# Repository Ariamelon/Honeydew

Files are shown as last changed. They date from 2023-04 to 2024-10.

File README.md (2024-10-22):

# Honeydew
~60% 63-key QMK-compatible unified split ergonomic keyboard with [VIK](https://github.com/sadekbaroudi/vik) module support.

## Disclaimer
This keyboard is licensed under CERN-OHL-S-2.0, runs [QMK Firmware](https://qmk.fm/) and is compatible with the [VIK](https://github.com/sadekbaroudi/vik) standard. The layout is based on the [Cantaloupe](https://github.com/Ariamelon/Cantaloupe) layout, but with each half rotated 15 degrees inwards. The CNC aluminium top half of the keyboard case in the image was sponsored by [PCBWay](https://www.pcbway.com/).

## Key Features
* Ergonomic unsplit 60-key vertically staggered layout with thumb cluster, pinky stagger and arrow keys, plus 3 keys around a center VIK module spot and a 2.25u key below that.
* Thumb scroll wheel at bottom of keyboard, replacing the 2.25u key in that position.
* Each half rotated 15 degrees inwards.
* On-board STM32F072RBT6 processor.
* SWD header for debugging purposes.
* USB-C input with full ESD protection.
* MX and choc hotswap switch support with kailh hotswap sockets.
* Per-key RGB backlight and ARGB header for adding more.
* Gasket-mount case supporting 65 x 4 x 4mm gaskets with 25% compression (14 required).
* [Acheron single-push reset circuit](https://acheronproject.com/reset_article_1/reset_article_1/#52-substituting-the-jfet).

## VIK keyboard certification card
| Category | Classification | Response |
| ---  | --- | --- |
| FPC connector | Required | :heavy_check_mark: |
| Breakout pins | Recommended | :heavy_check_mark: |
| Supplies: SPI | Strongly recommended | :heavy_check_mark: |
| Supplies: I2C | Strongly recommended | :heavy_check_mark: |
| I2C on main PCB | Discouraged | No |
| I2C pull ups | Informative | N/A |
| Supplies: RGB | Strongly recommended | :heavy_check_mark: |
| Supplies: Extra GPIO 1 | Required | Analog/Digital |
| Supplies: Extra GPIO 2 | Required | Analog/Digital |

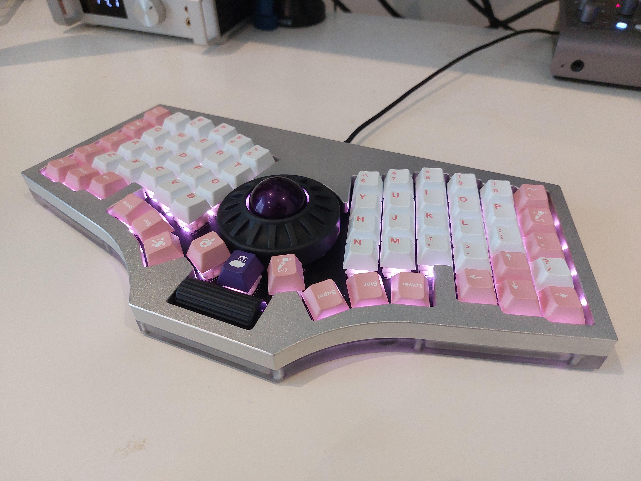
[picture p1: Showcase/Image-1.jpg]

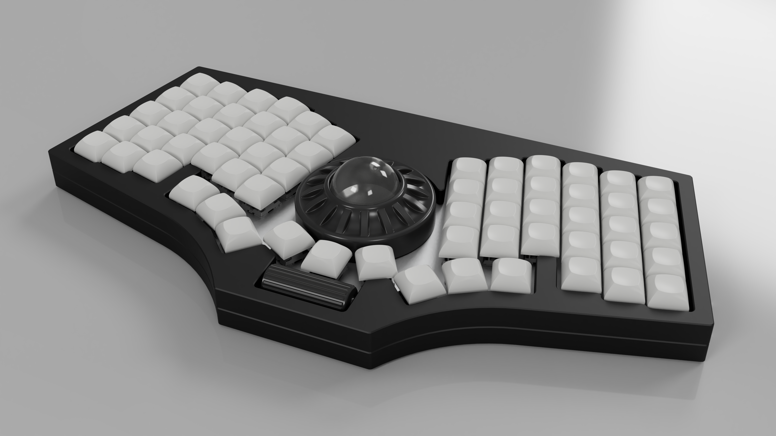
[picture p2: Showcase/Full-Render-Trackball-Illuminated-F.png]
Full Render Trackball Illuminated Front

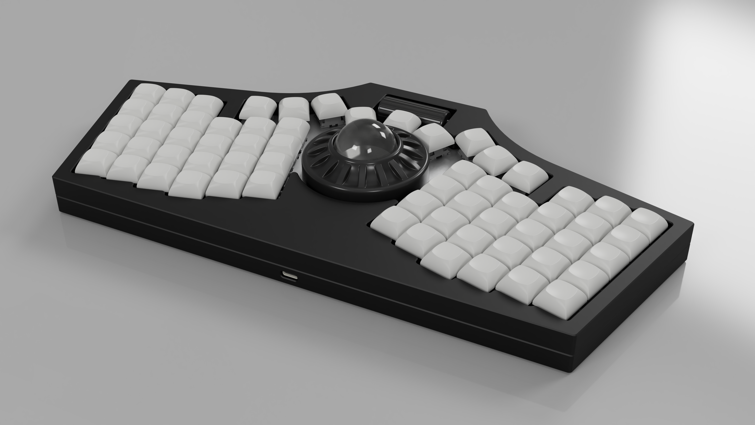
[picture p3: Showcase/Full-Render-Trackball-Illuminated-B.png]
Full Render Trackball Illuminated Back

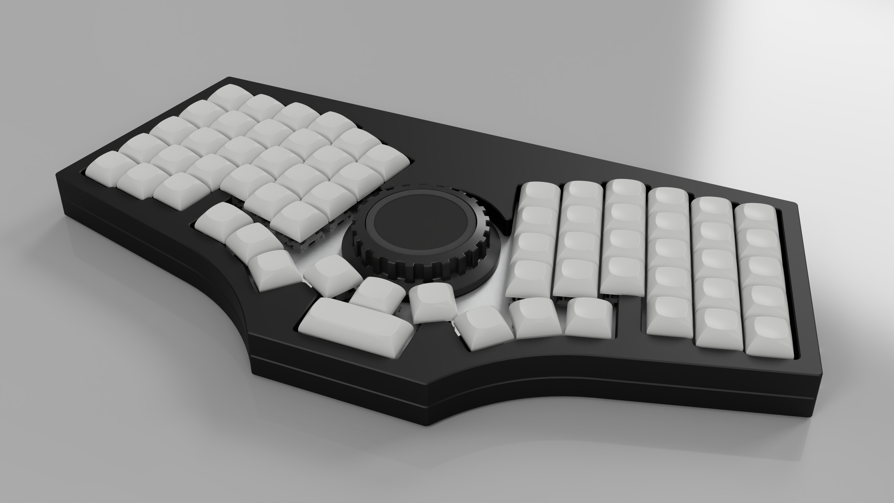
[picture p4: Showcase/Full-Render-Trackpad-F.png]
Full Render Trackpad Front

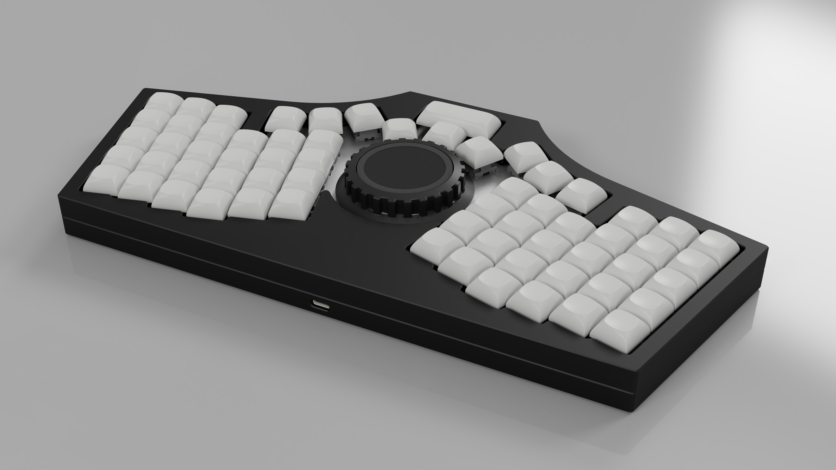
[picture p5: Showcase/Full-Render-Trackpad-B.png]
Full Render Trackpad Back

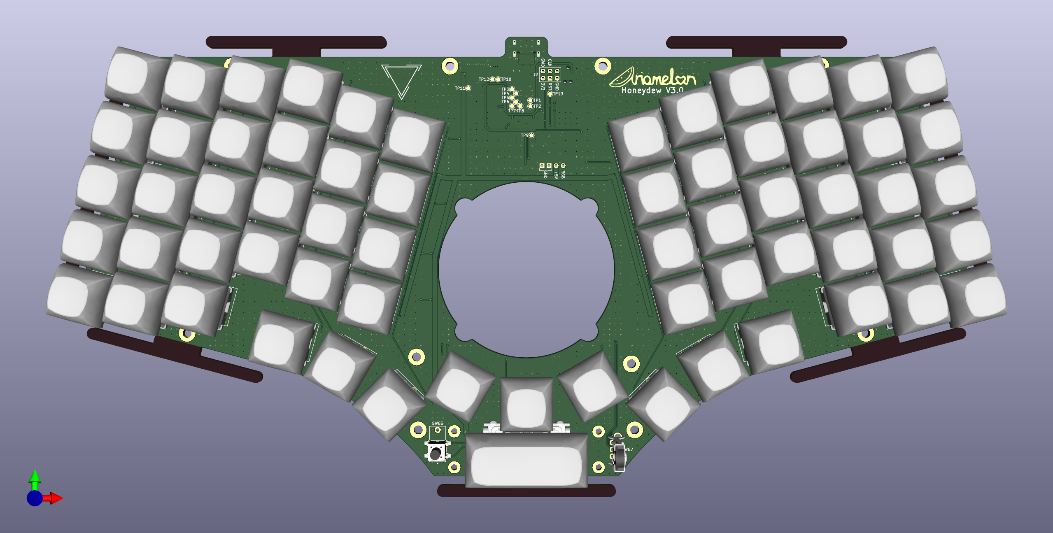
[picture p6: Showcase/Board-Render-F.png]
Board Render Front

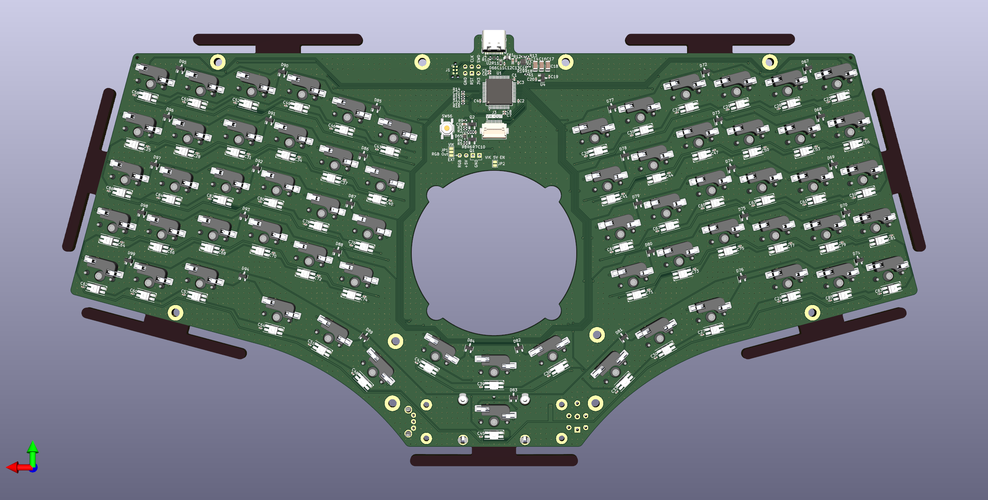
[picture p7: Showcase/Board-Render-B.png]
Board Render Back


## Changelog
* 22/10/2024: License updated to CERN-OHL-S-2.0.
* 29/09/2023: Added PCBWay sponsorship disclaimer to the readme. Updated library.
* 27/09/2023: Added image. Small change to scrollwheel 3D file for smoother scrolling.
* 18/09/2023: Fixed .gitignore file. Updated library.
* 02/09/2023: Added ribs to bottom case for less warping, deformation and shrinkage risk. Updated library.
* 29/08/2023: Reassigned I2C pins due to DMA issues and rerouted board. Added test point for BOOT0. Added additional ground vias.
* 28/08/2023: Added test points for VIK connector. Refined case and scrollwheel design. Added pull-up resistor to RGB trace. Added Acheron single-push reset circuit. Updated STEP files.
* 27/08/2023: Added unified library for all symbols, footprints and 3D files. Changed MCU to STM32F072RBT6. Removed OLED, voltage and current sensing, USB CC circuitry and shift registers. Changed ESD protection chip. Cleaned up routing and component placement. Changed SWD header pinout to 6-pin standard.
* 17/08/2023: Moved gasket mounts from plate to PCB. Changed USB C connector. Modified case to accommodate.
* 16/08/2023: Fixed VIK wiring (RGB and SDA were swapped). Added another BAV70 for the bottom button in the thumb cluster. Added DNP attribute to R15. Added jumper for VIK 5V rail. 
* 08/08/2023: Fixed case render.
* 06/08/2023: Changed switch footprint back to MX only, as it's too much money to risk on an experimental footprint, and rerouted the relevant traces. Cleaned up footprint library by removing many unused footprints.
* 05/08/2023: Fixed switch and SK6812 MINI-E footprints to get rid of DRC errors. Fixed EC10 footprint and merged together PTS645 and D2F footprints. Fixed plate files to fit JLC 1.6mm minimum slot specification. Added fusion file for overall design.
* 04/08/2023: Updated SK6812 MINI-E and switch footprints. Changed VIK FFC to FH12. Fixed VIK footprint. Replaced second TPS2595 with AO3401 PFET. Fixed trackpad mount, thumb scroll wheel and scroll wheel mount.
* 01/08/2023: Removed 3D files for trackpad mount and knob, moved to [Kiwano](https://github.com/Ariamelon/Kiwano) repository. Increased size of center hole in plate. Added renders with trackball configurations (refer to Kiwano).
* 31/07/2023: Removed button daughterboard. Reduced size of case and gaskets and added locating features. Added o-ring mounting for the PCB to the bottom case. Added fittings BOM.
* 30/07/2023: Added VIK keyboard certification card. Added USB connector back to PCB, but left the two buttons on a separate daughterboard. Modified case to accommodate large VIK module.
* 28/07/2023: Removed center ring encoder, cirque trackpad and PMW3360 support. Added VIK header and hole in the center of the PCB for the [Kiwano](https://github.com/Ariamelon/Kiwano). Changed JST connectors back to 20 pin FFC. Total rearrangement of parts in keyboard center. Stitched ground planes together. Added USB module to board rather than have it be separate.
* 26/07/2023: Slightly increased size of screw hole pads. Added two more screw holes. Added mounting holes to plate. Flipped gerbers for scrollwheel plate.
* 25/07/2023: Changed 8 pin JST SH connector to 6 pin. Pushed JST connectors back. Improved 3D model of SSD1351. Minor fix to PER56 footprint.
* 21/07/2023: Changed 20 pin FFC to 7 pin and 8 pin JST SH connector.
* 18/07/2023: Changed JST connector back to 20 pin FFC. Centered connector. Increased size of PMW3360 cutout.
* 17/07/2023: Changed 20 pin FFC connector to 14 pin JST SH connector. Repositioned components.
* 16/07/2023: Updated case file. Added individual case files. Added kicad plate files.
* 14/07/2023: Replaced 1N4148 switch diodes with BAV70. Replaced switch footprints with combination MX/Choc hotswap footprints. Replaced flash IC with much smaller version. Removed buttons and USB-C port and replaced it with an FFC connector for [Galia](https://github.com/Ariamelon/Galia) (a USB-C daughterboard designed specifically for the Honeydew). Added case STEP file and renders. Added footprint for PTS645 SMT and THT parts to the mouse switch in the thumb encoder.
* 06/07/2023: Replaced 0805 ferrite with 1206. Repositioned components.
* 30/06/2023: Routed 13V EN pin to the MCU. Removed 13V solder jumper.
* 27/06/2023: V3.0 initial update. Wired RST pin of OLED to MCU. Reduced size of OLED FFC cutout. Repositioned components. Added REF3033 3.3V voltage reference and connected it to the ADC input. Added pullup to RGB current limit switch enable input. 
* 11/06/2023: Updated BOM. Added new tentative plate file. Updated 3D files.
* 20/05/2023: Added scroll wheel rotary encoder and mouse switch for thumb scroll wheel, replacing bottom 2u key.
* 19/05/2023: Improved switch footprints. Changed 3v3 regulator to XC6206P332MR.
* 15/05/2023: Finished routing RGB LEDs.
* 05/05/2023: Changed PMOS switch to TPS2595, set to ~3A current limit. Got rid of RGB current measurement. Added enable jumper for 13V OLED PSU (only jump when in use to reduce noise when not in use). Still not done with RGB LED routing.
* 25/04/2023: Added current and voltage measurement for VBUS in and current measurement for the RGB output. Added PMOS power switch to fully turn off RGB LEDs when not in use. Rerouted the PCB. Moved OLED ribbon cable cutout and expanded it length-wise. Changed position of various components for better routing. Changed bulk capacitance of RGB LEDs to 5 x 22u capacitors. Changed the four N mosfets to two much smaller dual N mosfets. Still need to do RGB routing!
* 17/04/2023: Large update. Changed position of thumb buttons and added another button. Revamped shape of PCB again. Changed PER60 to PER56. Added 30-pin FFC receptacle for direct OLED panel mounting to the PCB (lower profile). Now using 595 shift registers for columns. Increased number of LEDs in central LED ring. Changed current limiting device to TPS2595. Connected current limiting ICs to MCU, allowing for software monitoring of current levels and changing of allowed current. Removed individual RGB capacitors and added bulk capacitance.
* 10/04/2023: Shrunk size of PCB. Added plate DXF and gerbers. Removed split comms ports and ideal diode.
* 08/04/2023: Large update. Removed single-push reset circuit, added side buttons next to the USB ports. Added pi filter to VBUS and split comms ports for more voltage filtering. Completely revamped shape of PCB for more space efficiency. Pushed each side further out and OLED further down. Added TUSB320 CC logic controller and TPS2557 current limit switch to allow the board to safely draw up to 15W (5V 3A) of power. Added mounting holes on PCB. Removed ferrite between USB shield and ground. Replaced back to back P-mosfets with ideal diode setup. Removed QMK logo (sorry). Cleaned up schematic somewhat. Added large caps to output of TPS2557. Updated STEP file and file data. Added back ground plane. Fixed rotation of production files.
* 03/04/2023: Changed level shifter to cheaper model. Slightly changed USB-C footprint. Added single-push reset circuit and removed DIP switch. Updated readme and STEP file. Moved position of USB-C ports further out.
* 02/04/2023: Changed angle of each unsplit half to 15 degrees inwards instead of 20 degrees with corresponding change to PCB and plate shape. Re-did 5V routing on the board. Added ARGB header to attach external RGB strips. Removed reverse voltage/current schottky and added back to back P-mosfets to provide the same function. Added ferrite bead to VBUS for more voltage filtering. Changed ESD protection chip to TPD4E05U06DQAR. Added USB-C expansion headers for expansion boards using split comms with the same protections as the primary USB-C input port. Added M3 earth pad for connection to a metal case. Added solder jumper to select OLED voltage as it should work fine when powered by 5V, but the option to power from 3V3 is there if required. Case to follow..
* 31/03/2023: Connected DR (data-ready) pin of TM040040 to Motion pin of PMW3360 as they serve the same function. Connected reset pins to hardware reset button instead of MCU. Added locating features to CNC case, increased wall thickness by 1mm for better magnet support (4mm now instead of 3mm) and increased size of gaskets. Redesigned trackpad mount and rotary encoder knob to allow for the illuminated ring to show up better. Added powered by QMK logo to board.
* 24/04/2023: Added level shifter to the RGB signal, just in case.
* 14/03/2023: Fixed top and bottom case STEP files. Minor fix to silk.
* 13/03/2023: V2.0 initial update. Moved switch footprint center back to normal position. Swapped capacitor and resistor at USB-C connector for ferrite bead. Moved positions of USB VBUS protection. 
* 11/03/2023: Added PH2.0 header for OLED. Changed plate to accommodate headers. Better render.
* 10/03/2023: Fixed OLED description in readme. Changed center of switches for JLC assembly.
* 09/03/2023: Shifted MCU up to reduce length of USB traces. Added holes for JLC assembly. Attempted to render a better quality image.
* 08/03/2023: Added 3D render of case, case STEP files and plate DXF and gerbers.
* 07/03/2023: Rewording of readme. Added files for JLC PCBA. Changed USB C connector and moved it away from board.
* 06/03/2023: Minor repositioning of parts.
* 05/03/2023: Added mounting holes for trackpad/trackball mount. Added CC BY 4.0 license.
* 04/03/2023: Massive mistake corrections and clarifications. Changed 22R USB resistors to 27R. Readded missing pullup for RUN pin. Changed notation of power and ground rails to the standard. Connected RGB LEDs to 5V instead of 3V3. Added keycap model to render. Changed board showcase files from SVG to PDF. Fixed error in MCU sheet. Changed flash symbol to the one used in Kicad 7.
* 03/03/2023: Initial public upload of V1.0.

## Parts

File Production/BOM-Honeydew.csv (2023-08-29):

Comment | Designator | Footprint | LCSC
1k | R4 | R_0402_1005Metric | C11702
10n | C11,C21,C22,C8 | C_0402_1005Metric | C15195
1u | C12 | C_0603_1608Metric | C15849
USB In | J4 | G-Switch_GT-USB-7010ASV | C165948
AO3400A | Q1,Q2 | SOT-23-3 | C20917
1N4148 | D65 | D_SOD-323 | C2128
TPS259533 | U3 | WSON-8-1EP_2x2mm_P0.5mm_EP0.9x1.6mm | C2155777
60R@100MHz | FB1 | L_0805_2012Metric | C237300
4u7 | C1,C5 | C_0402_1005Metric | C23733
100 | R7 | R_0402_1005Metric | C25076
100k | R8 | R_0402_1005Metric | C25741
10k | R13,R14,R15,R16,R17,R5,R6,R9 | R_0402_1005Metric | C25744
12k | R18 | R_0402_1005Metric | C25752
330k | R2 | R_0402_1005Metric | C25778
5k1 | R1,R10,R11 | R_0402_1005Metric | C25905
6k8 | R19 | R_0402_1005Metric | C25917
1M | R3 | R_0402_1005Metric | C26083
100n | C10,C13,C14,C2,C23,C24,C25,C26,C27,C28,C29,C3,C30,C31,C32,C33,C34,C35,C36,C37,C38,C39,C4,C40,C41,C42,C43,C44,C45,C46,C47,C48,C49,C50,C51,C52,C53,C54,C55,C56,C57,C58,C59,C6,C60,C61,C62,C63,C64,C65,C66,C67,C68,C69,C70,C71,C72,C73,C74,C75,C76,C77,C78,C79,C80,C81,C82,C83,C84,C85,C86 | C_0402_1005Metric | C307331
Reset | SW66 | SW_SPST_TL3342 | C318884
STM32F072RBT6 | U1 | LQFP-64_10x10mm_P0.5mm | C46046
SK6812MINI-E | D1,D10,D11,D12,D13,D14,D15,D16,D17,D18,D19,D2,D20,D21,D22,D23,D24,D25,D26,D27,D28,D29,D3,D30,D31,D32,D33,D34,D35,D36,D37,D38,D39,D4,D40,D41,D42,D43,D44,D45,D46,D47,D48,D49,D5,D50,D51,D52,D53,D54,D55,D56,D57,D58,D59,D6,D60,D61,D62,D63,D64,D7,D8,D9 | LED_OPSCO_SK6812MINI-E | C524051
1u | C15,C19,C20,C7 | C_0402_1005Metric | C52923
XC6206P332MR | U4 | SOT-23-3 | C5446
BAV70 | D67,D68,D69,D70,D71,D72,D73,D74,D75,D76,D77,D78,D79,D80,D81,D82,D83,D84,D85,D86,D87,D88,D89,D90,D91,D92,D93,D94,D95,D96,D97,D98,D99 | SOT-23-3 | C68978
5V | D66 | D_SOD-523 | C85708
VIK Keyboard Expansion | J3 | VIK_Keyboard_Horizontal | C88360
TPD2EUSB30A | U2 | Texas_DRT-3 | C94934
47u | C16,C17,C18 | C_1206_3216Metric | C96123
10u | C9 | C_0603_1608Metric | C96446
SWD | J2 | PinHeader_SWD_2x03_P2.54mm_Vertical
CPG151101S11 | SW25 | SW_MX_1U_Hotswap
CPG151101S11 | SW30 | SW_MX_1U_Hotswap
CPG151101S11 | SW1 | SW_MX_1U_Hotswap
CPG151101S11 | SW24 | SW_MX_1U_Hotswap
CPG151101S11 | SW29 | SW_MX_1U_Hotswap
CPG151101S11 | SW14 | SW_MX_1U_Hotswap
CPG151101S11 | SW19 | SW_MX_1U_Hotswap
CPG151101S11 | SW5 | SW_MX_1U_Hotswap
CPG151101S11 | SW22 | SW_MX_1U_Hotswap
CPG151101S11 | SW27 | SW_MX_1U_Hotswap
CPG151101S11 | SW3 | SW_MX_1U_Hotswap
CPG151101S11 | SW8 | SW_MX_1U_Hotswap
CPG151101S11 | SW13 | SW_MX_1U_Hotswap
CPG151101S11 | SW23 | SW_MX_1U_Hotswap
CPG151101S11 | SW18 | SW_MX_1U_Hotswap
CPG151101S11 | SW28 | SW_MX_1U_Hotswap
CPG151101S11 | SW4 | SW_MX_1U_Hotswap
CPG151101S11 | SW9 | SW_MX_1U_Hotswap
CPG151101S11 | SW10 | SW_MX_1U_Hotswap
CPG151101S11 | SW15 | SW_MX_1U_Hotswap
CPG151101S11 | SW20 | SW_MX_1U_Hotswap
CPG151101S11 | SW11 | SW_MX_1U_Hotswap
CPG151101S11 | SW2 | SW_MX_1U_Hotswap
CPG151101S11 | SW12 | SW_MX_1U_Hotswap
CPG151101S11 | SW21 | SW_MX_1U_Hotswap
CPG151101S11 | SW17 | SW_MX_1U_Hotswap
CPG151101S11 | SW16 | SW_MX_1U_Hotswap
CPG151101S11 | SW6 | SW_MX_1U_Hotswap
CPG151101S11 | SW7 | SW_MX_1U_Hotswap
CPG151101S11 | SW26 | SW_MX_1U_Hotswap
CPG151101S11 | SW56 | SW_MX_1U_Hotswap
CPG151101S11 | SW62 | SW_MX_1U_Hotswap
CPG151101S11 | SW50 | SW_MX_1U_Hotswap
CPG151101S11 | SW44 | SW_MX_1U_Hotswap
CPG151101S11 | SW42 | SW_MX_1U_Hotswap
CPG151101S11 | SW63 | SW_MX_1U_Hotswap
CPG151101S11 | SW61 | SW_MX_1U_Hotswap
CPG151101S11 | SW58 | SW_MX_1U_Hotswap
CPG151101S11 | SW34 | SW_MX_1U_Hotswap
CPG151101S11 | SW53 | SW_MX_1U_Hotswap
CPG151101S11 | SW45 | SW_MX_1U_Hotswap
CPG151101S11 | SW33 | SW_MX_1U_Hotswap
CPG151101S11 | SW48 | SW_MX_1U_Hotswap
CPG151101S11 | SW32 | SW_MX_1U_Hotswap
CPG151101S11 | SW37 | SW_MX_1U_Hotswap
CPG151101S11 | SW49 | SW_MX_1U_Hotswap
CPG151101S11 | SW46 | SW_MX_1U_Hotswap
CPG151101S11 | SW55 | SW_MX_1U_Hotswap
CPG151101S11 | SW41 | SW_MX_1U_Hotswap
CPG151101S11 | SW36 | SW_MX_1U_Hotswap
CPG151101S11 | SW35 | SW_MX_1U_Hotswap
CPG151101S11 | SW52 | SW_MX_1U_Hotswap
CPG151101S11 | SW39 | SW_MX_1U_Hotswap
CPG151101S11 | SW40 | SW_MX_1U_Hotswap
CPG151101S11 | SW43 | SW_MX_1U_Hotswap
CPG151101S11 | SW38 | SW_MX_1U_Hotswap
CPG151101S11 | SW60 | SW_MX_1U_Hotswap
CPG151101S11 | SW59 | SW_MX_1U_Hotswap
CPG151101S11 | SW47 | SW_MX_1U_Hotswap
CPG151101S11 | SW31 | SW_MX_1U_Hotswap
CPG151101S11 | SW64 | SW_MX_2U_Hotswap
CPG151101S11 | SW51 | SW_MX_1U_Hotswap
CPG151101S11 | SW54 | SW_MX_1U_Hotswap
CPG151101S11 | SW57 | SW_MX_1U_Hotswap

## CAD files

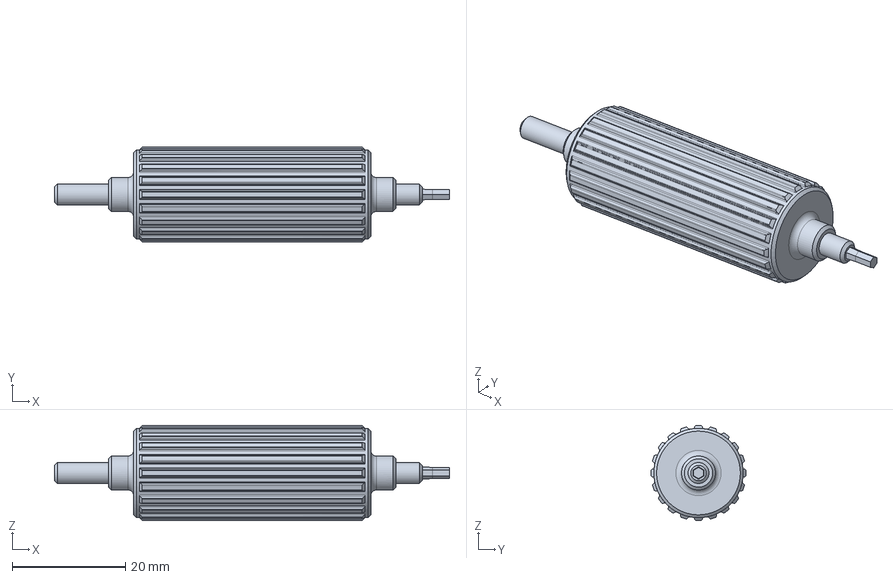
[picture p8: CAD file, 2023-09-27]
Case/Scrollwheel.step
69.8 x 16.8 x 16.8 mm

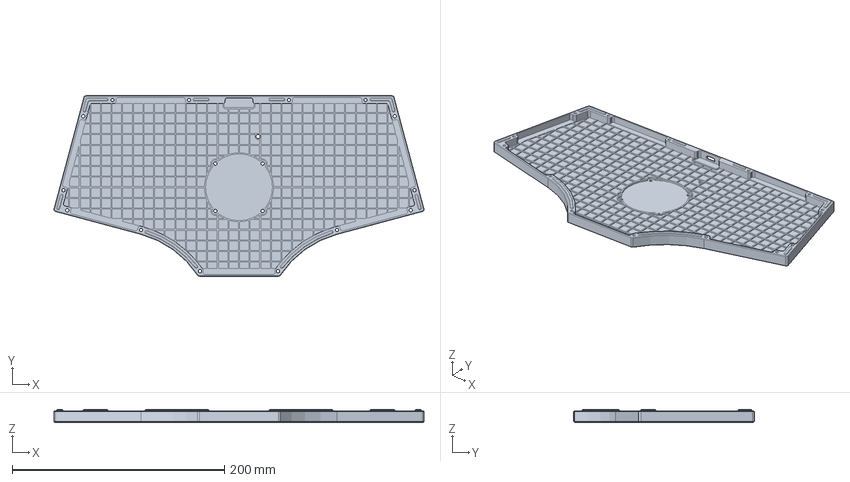
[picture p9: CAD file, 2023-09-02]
Case/Case Bottom.step
348.5 x 170.0 x 11.8 mm

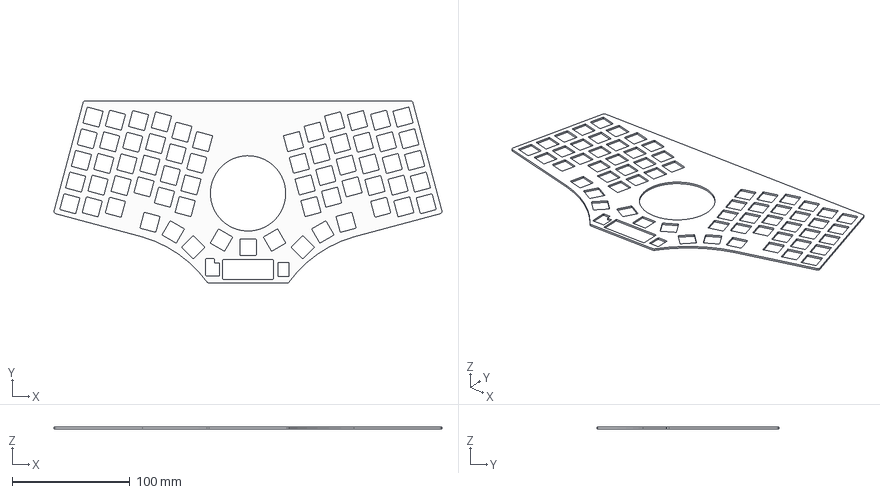
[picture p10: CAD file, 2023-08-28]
Case/Plate Scroll.step
329.6 x 154.8 x 1.50 mm

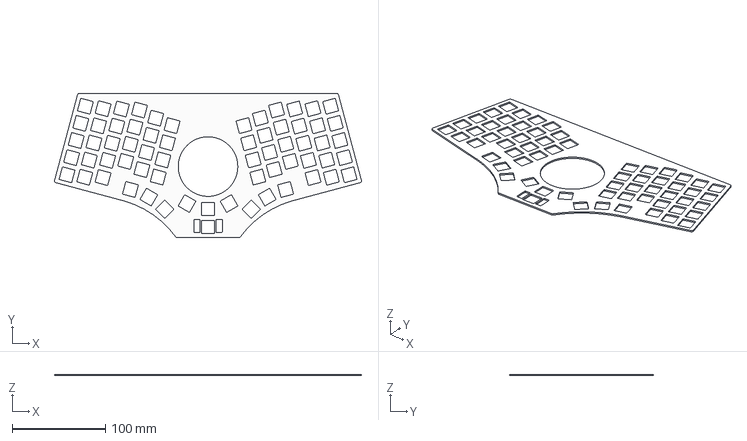
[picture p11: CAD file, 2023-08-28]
Case/Plate 2u.step
329.6 x 154.8 x 1.50 mm

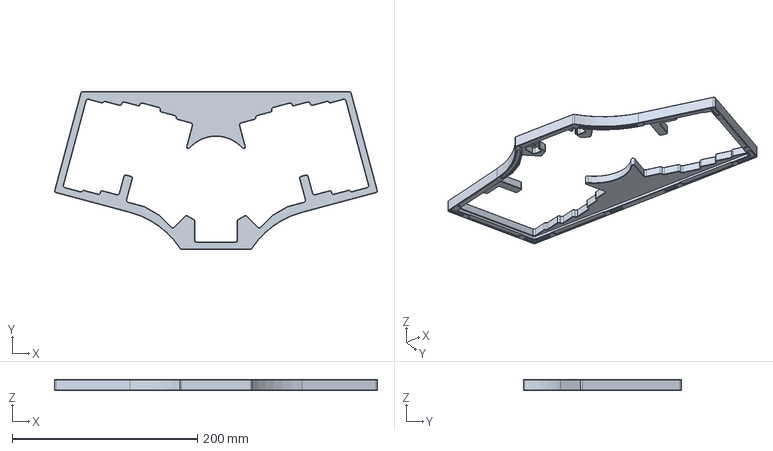
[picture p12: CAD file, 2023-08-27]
Case/Case Top.step
348.5 x 170.0 x 12.2 mm

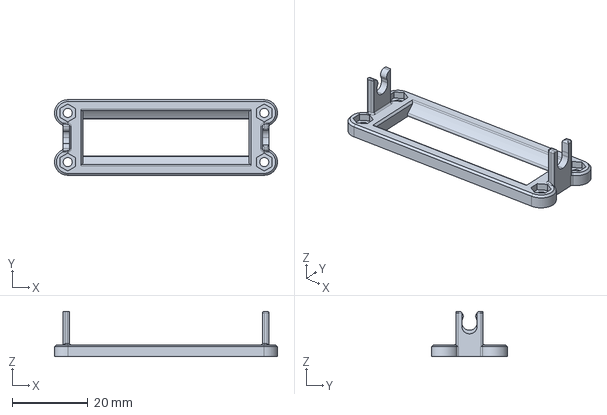
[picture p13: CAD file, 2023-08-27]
Case/Scrollwheel Holder.step
59.0 x 20.0 x 12.0 mm

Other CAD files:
Case/Plate 2u.dxf
Case/Plate Scroll.dxf

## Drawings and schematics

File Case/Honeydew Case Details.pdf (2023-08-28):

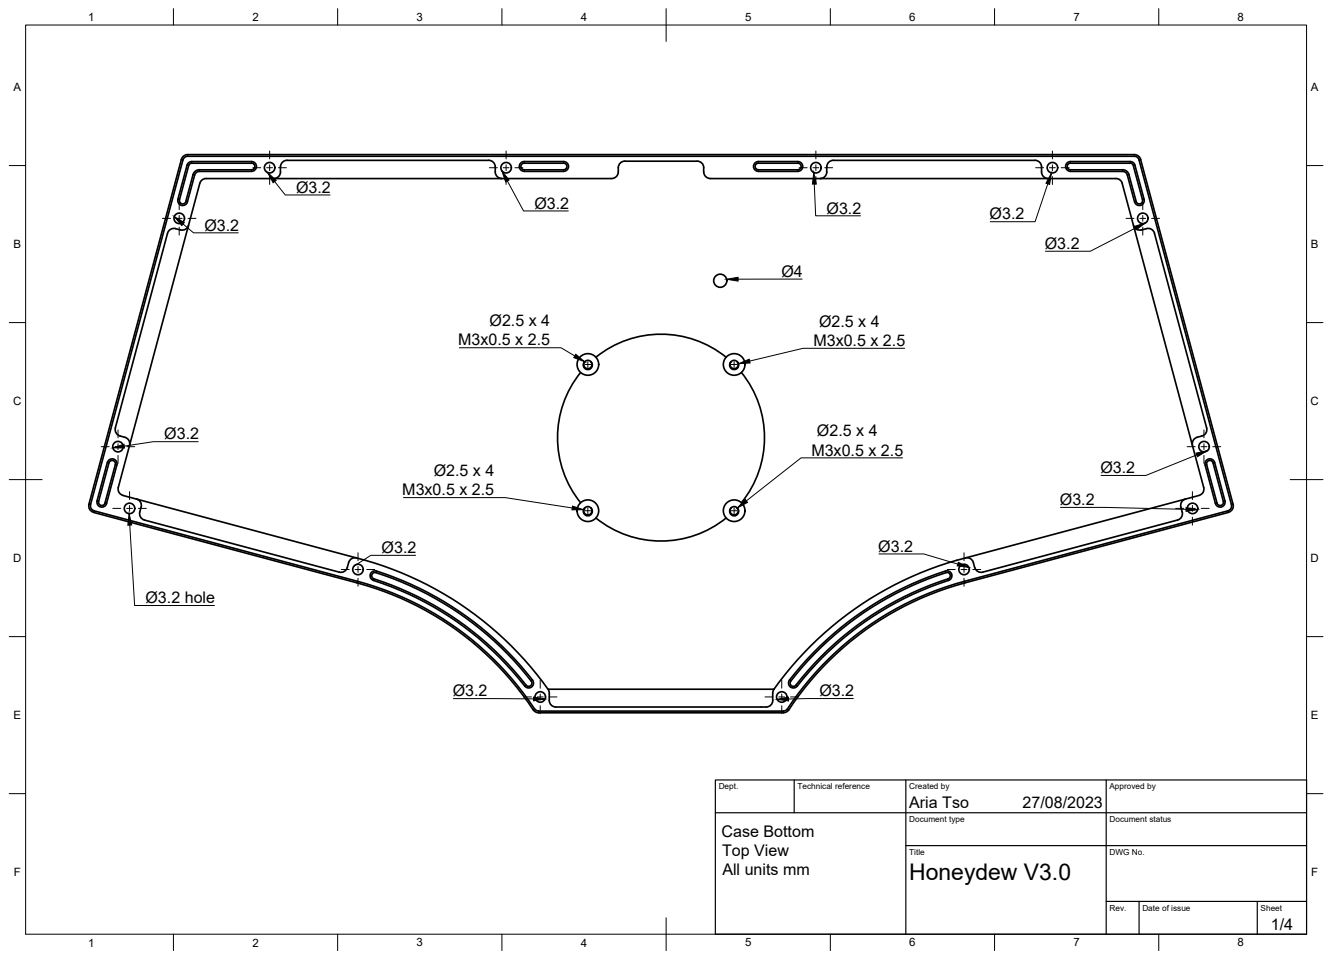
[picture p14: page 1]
Title; DWG No.; Rev.; Date of issue; Sheet; Honeydew V3.0; Ø3.2 hole

Dept. | Technical reference | Created by Aria Tso 27/08/2023 | Approved by

Document type | Document status

Case Bottom
Top View
All units mm

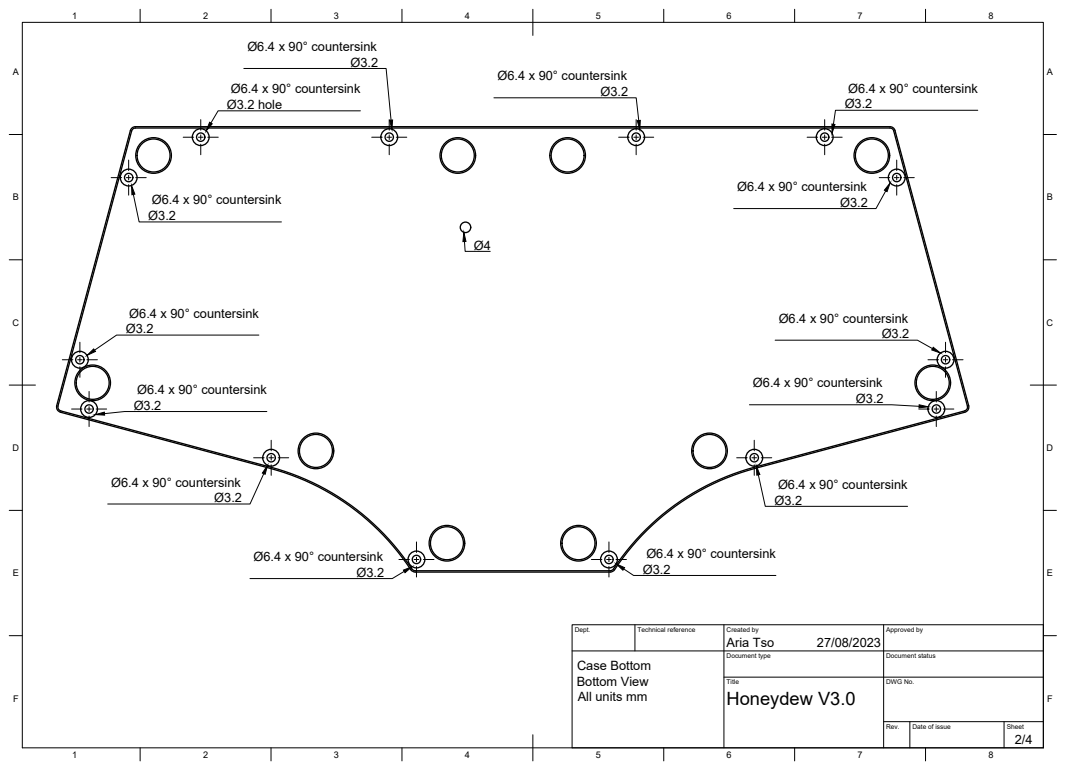
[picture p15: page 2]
Title; DWG No.; Honeydew V3.0; Ø6.4 x 90° countersink; Ø6.4 x 90° countersink Ø3.2 hole

Dept. | Technical reference | Created by Aria Tso 27/08/2023 | Approved by

Document type | Document status

Case Bottom
Bottom View
All units mm

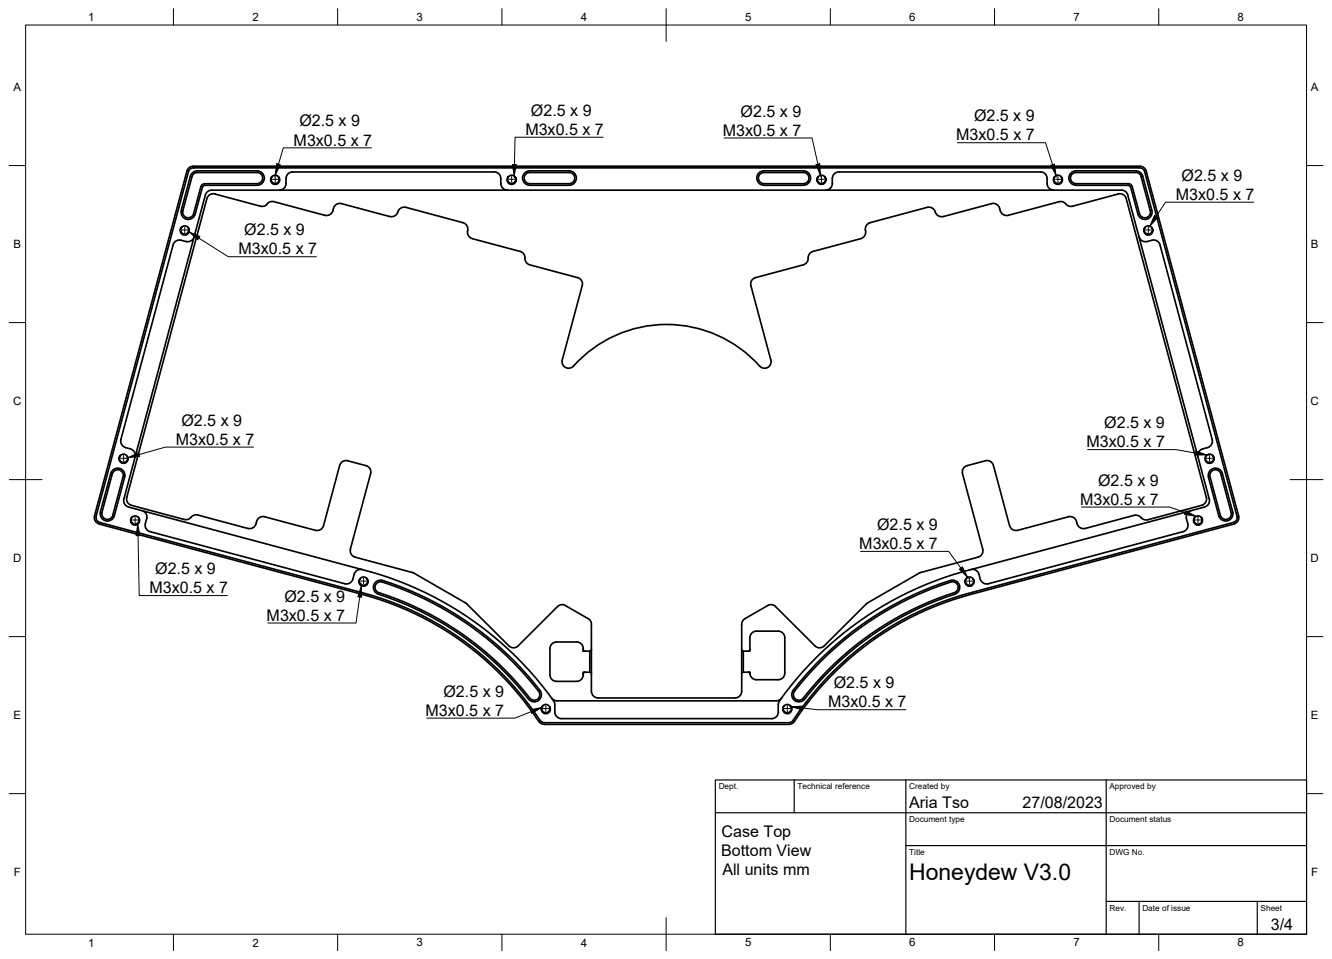
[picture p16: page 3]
Title; DWG No.; Honeydew V3.0

Dept. | Technical reference | Created by Aria Tso 27/08/2023 | Approved by

Document type | Document status

Case Top
Bottom View
All units mm

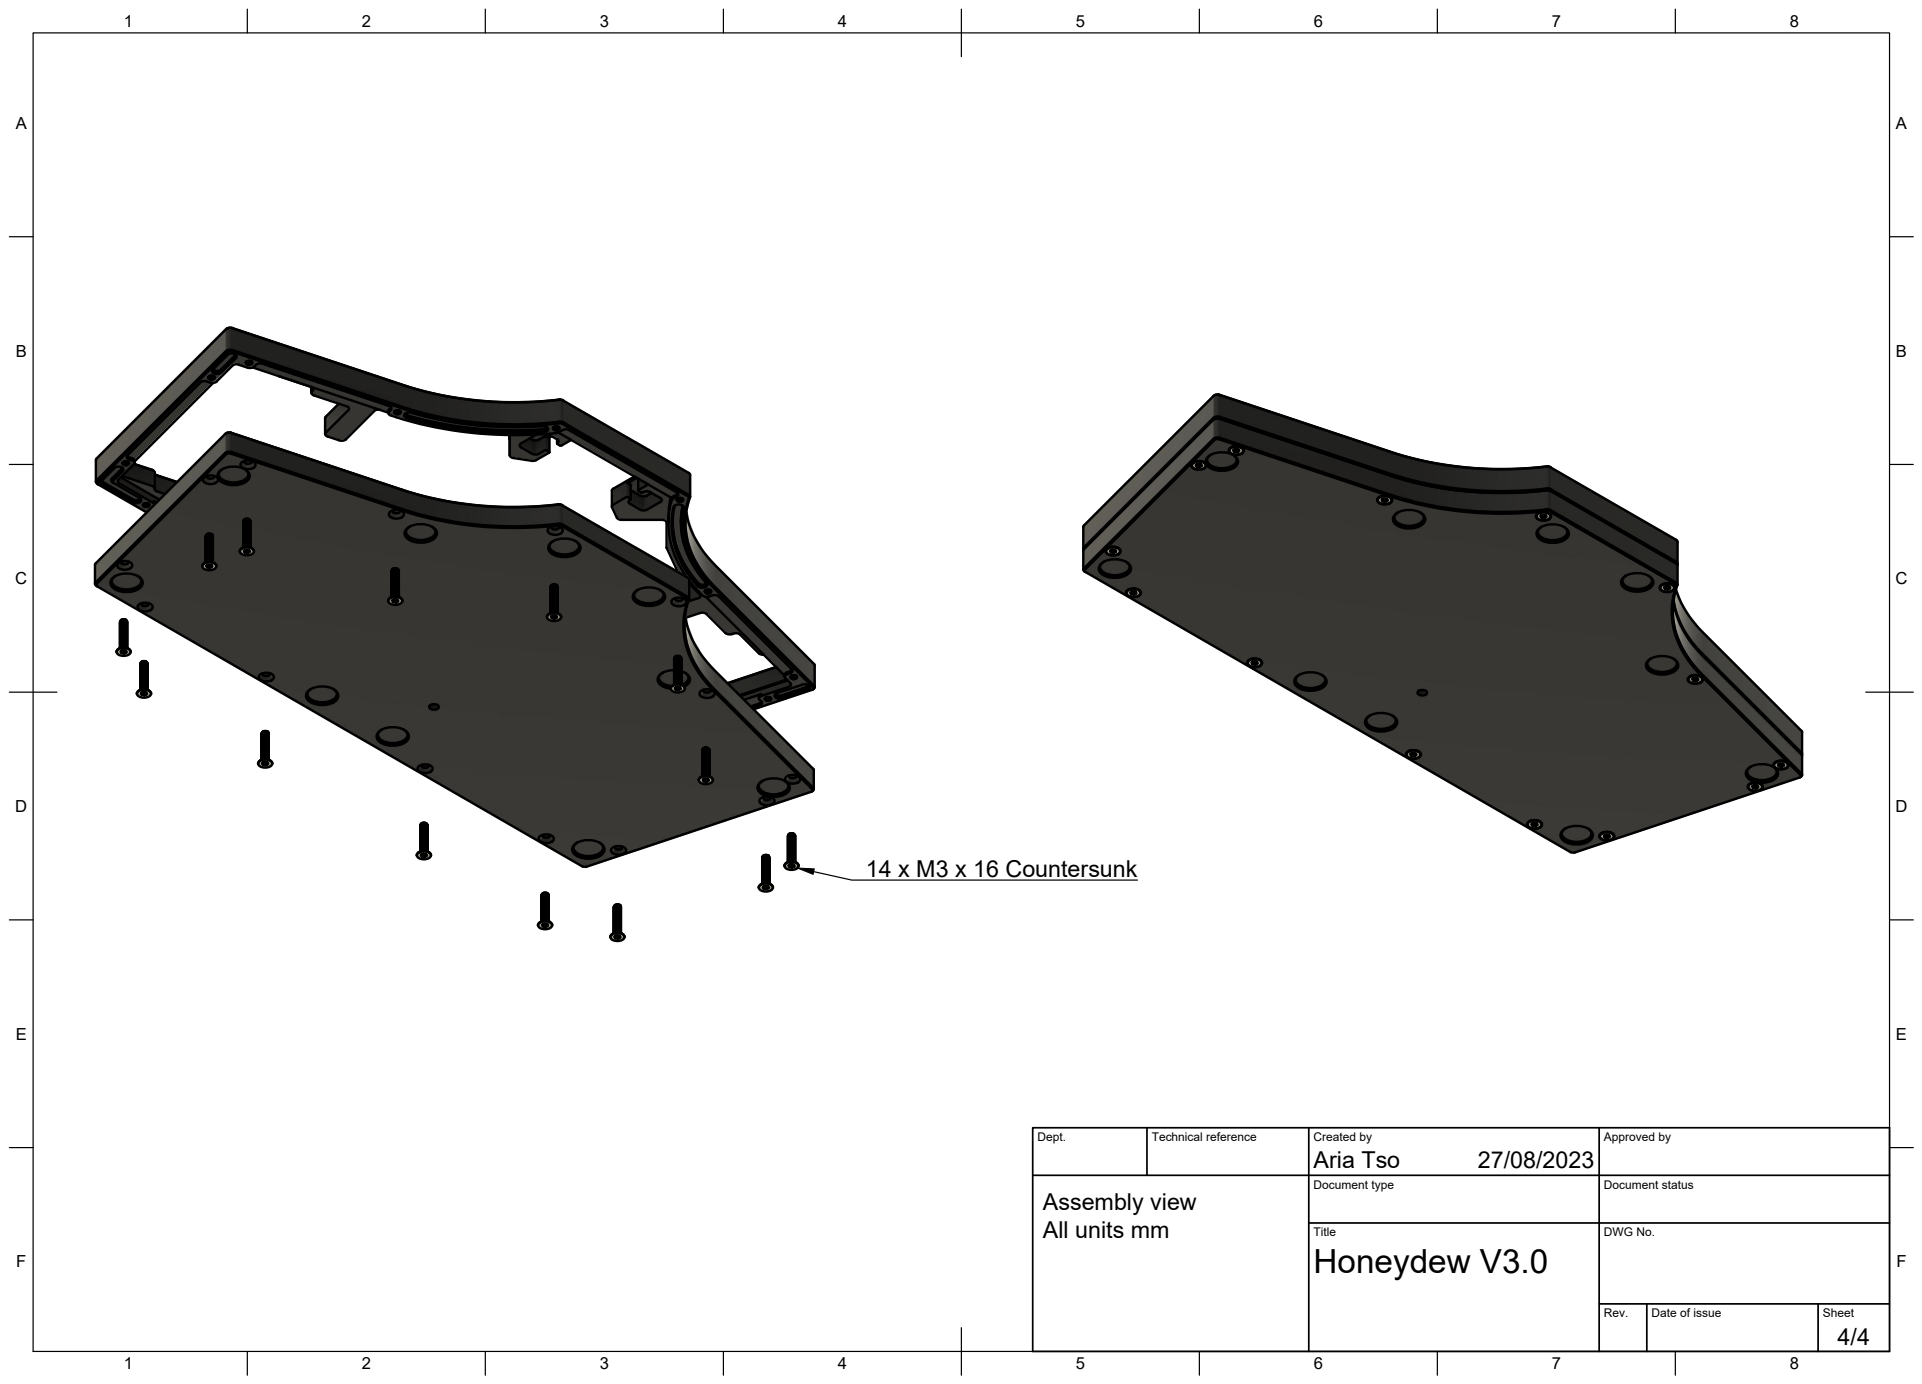
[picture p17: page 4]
Title; DWG No.; Honeydew V3.0; 14 x M3 x 16 Countersunk

Dept. | Technical reference | Created by Aria Tso 27/08/2023 | Approved by

Document type | Document status

Assembly view
All units mm

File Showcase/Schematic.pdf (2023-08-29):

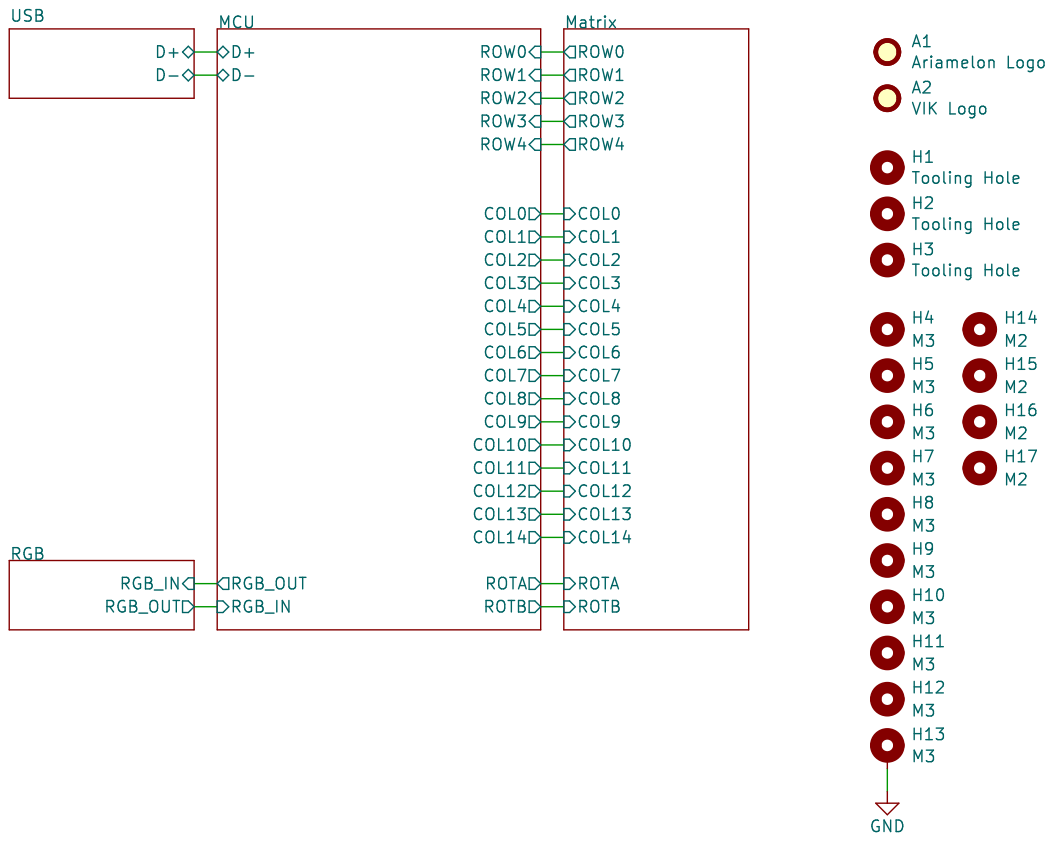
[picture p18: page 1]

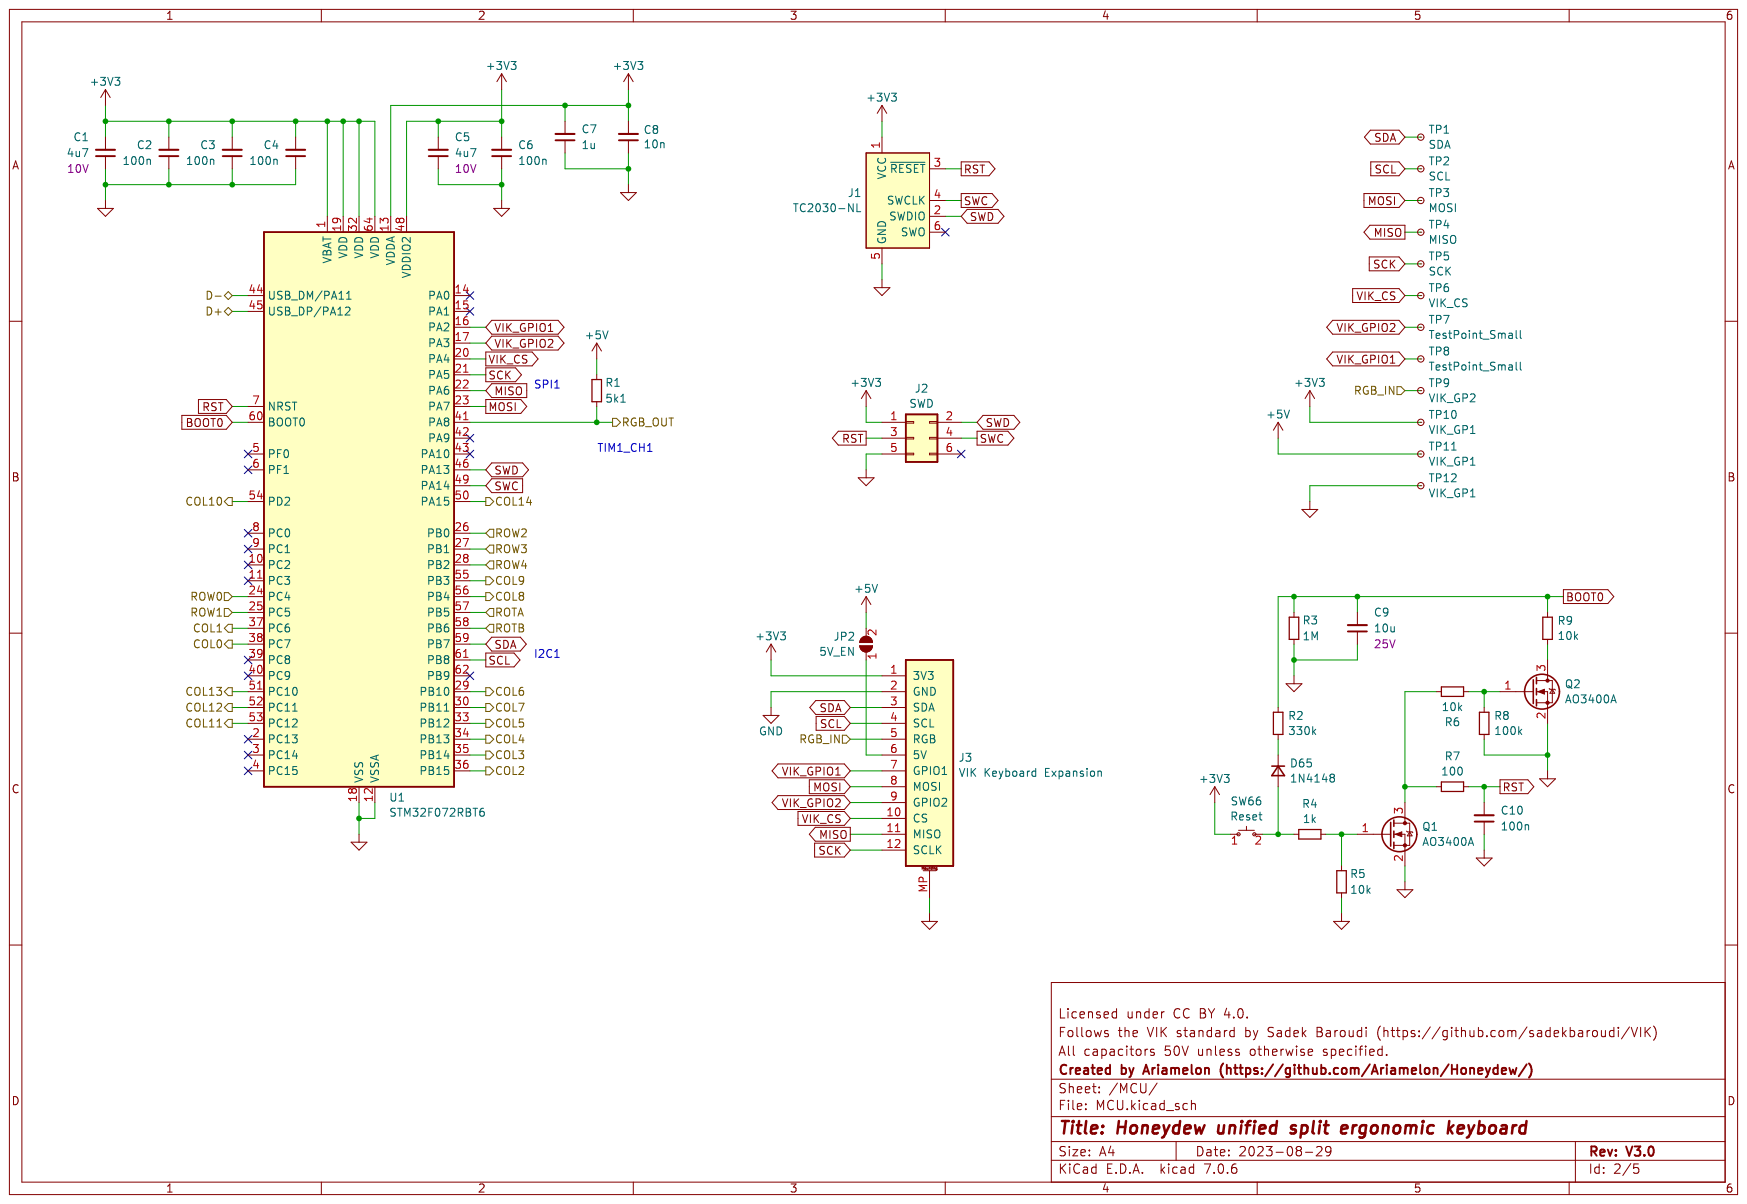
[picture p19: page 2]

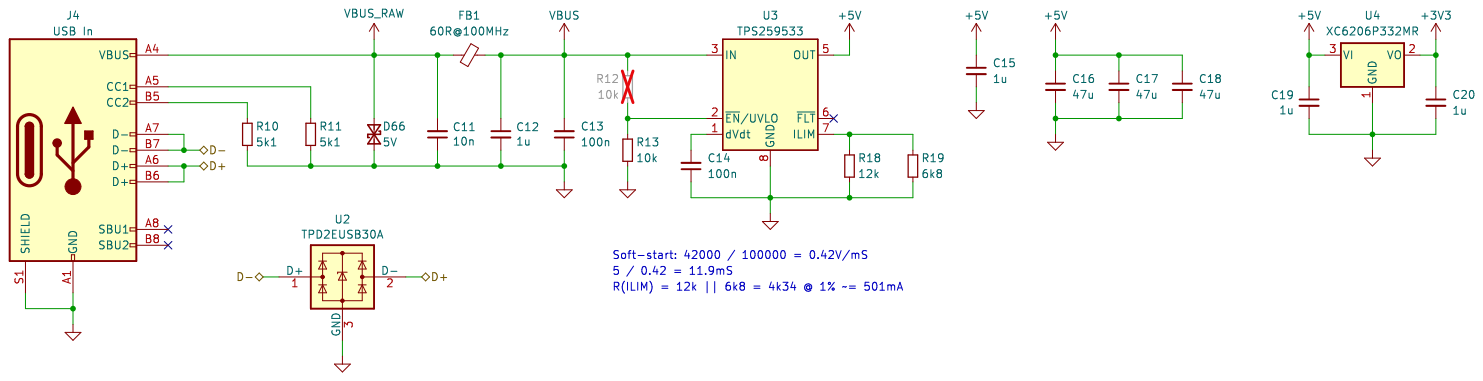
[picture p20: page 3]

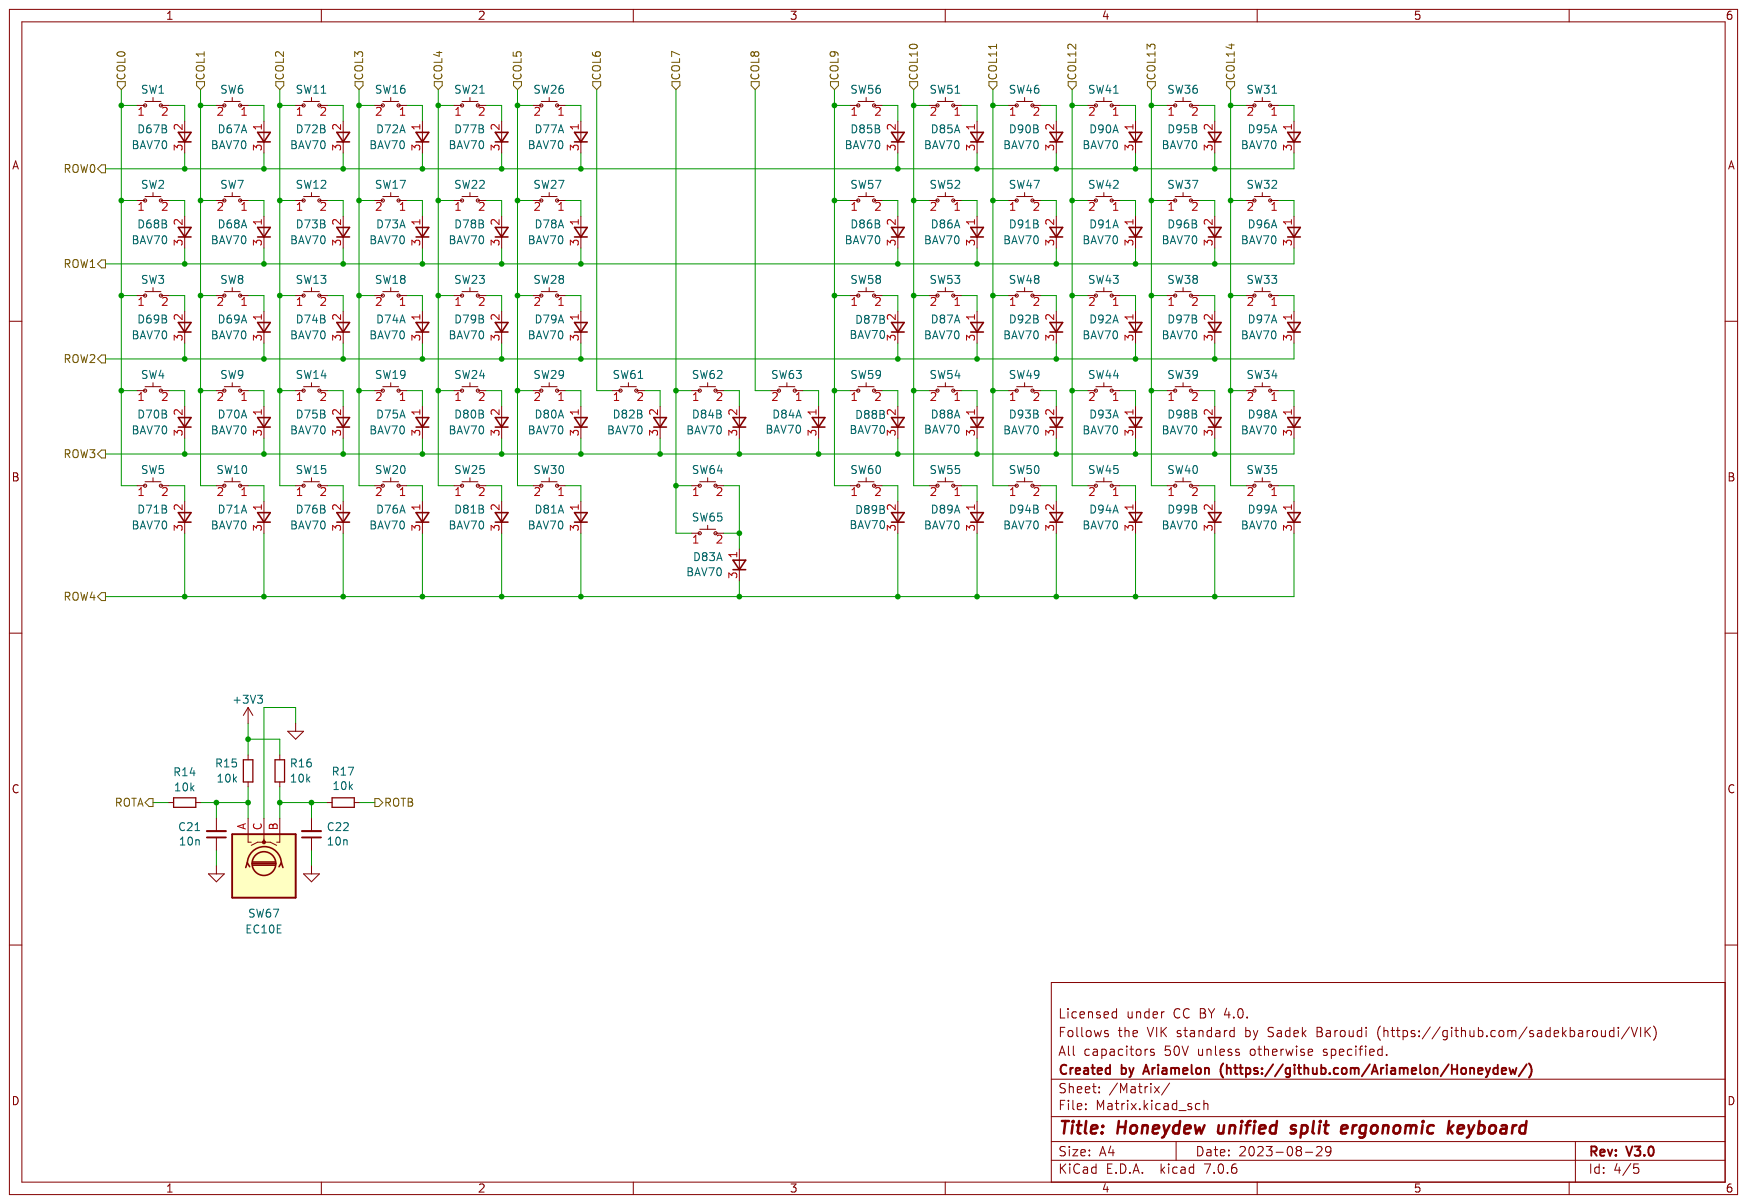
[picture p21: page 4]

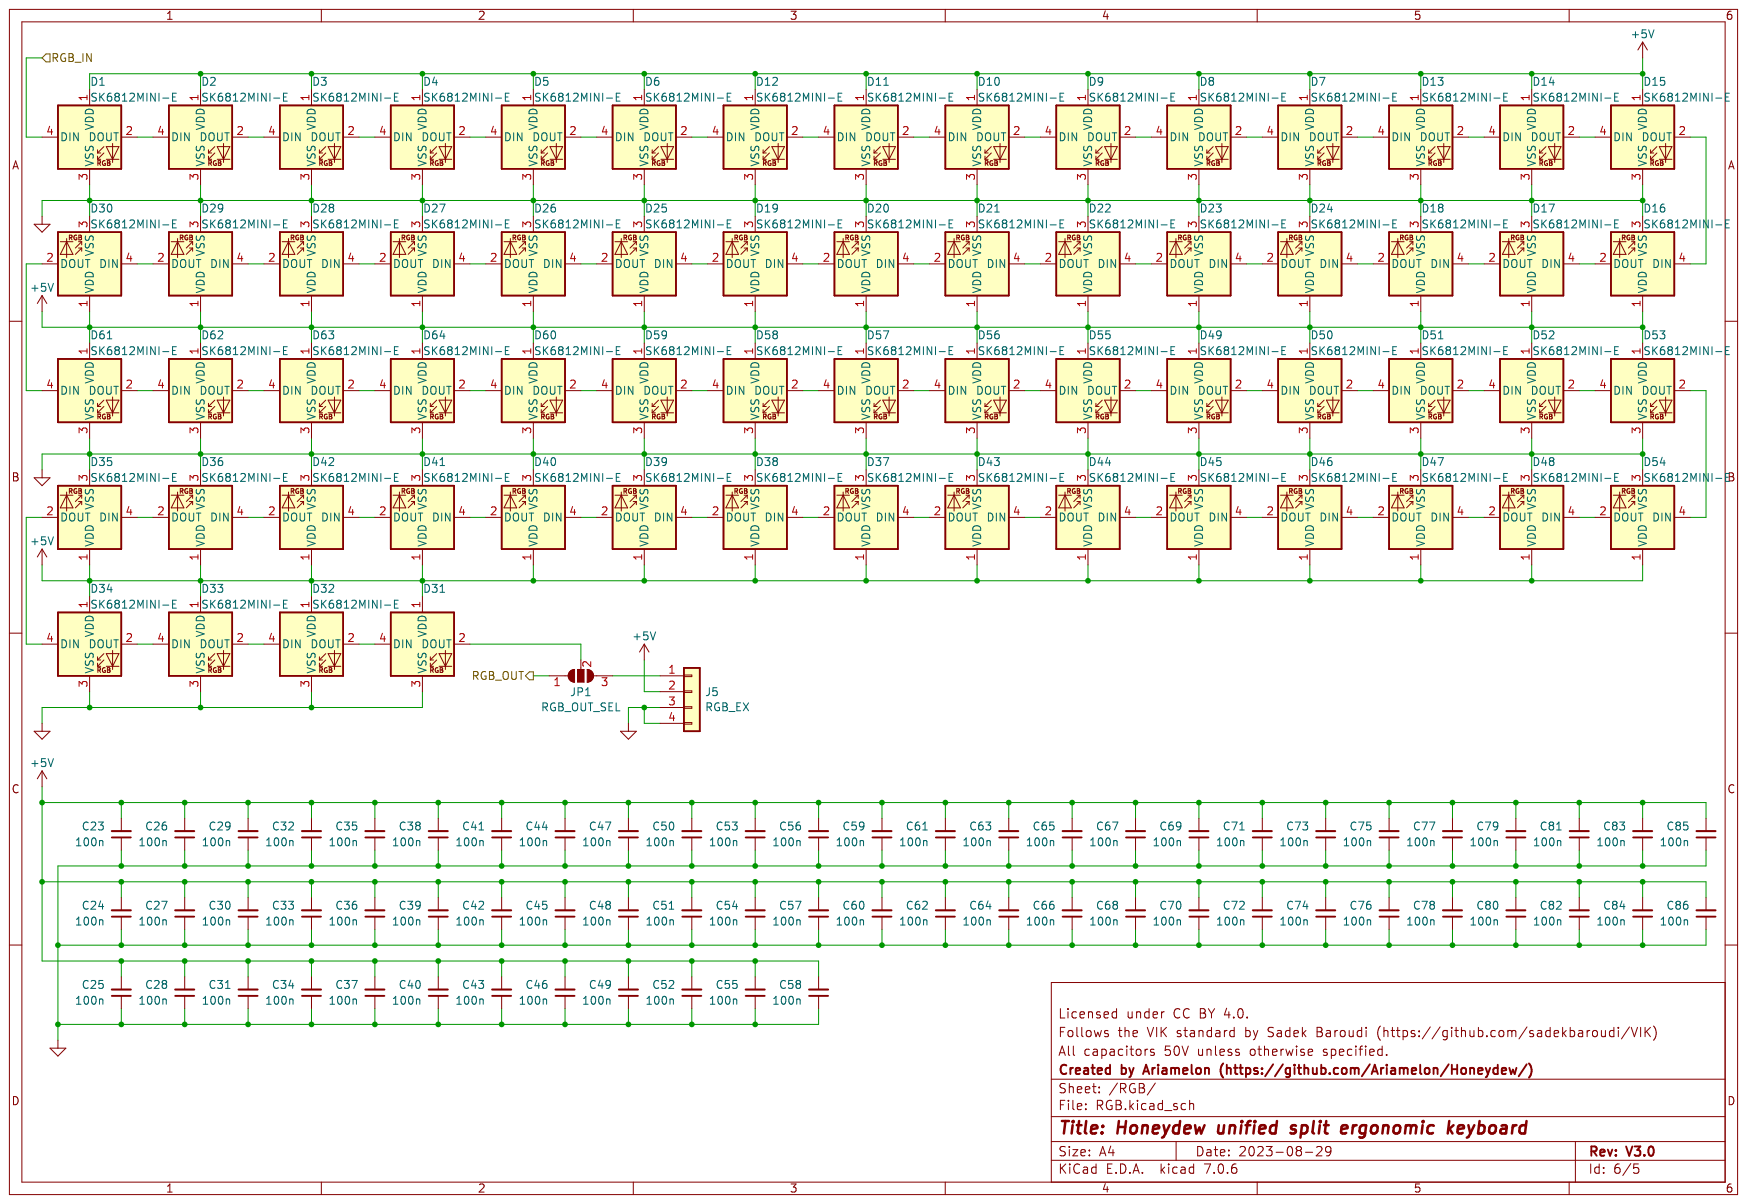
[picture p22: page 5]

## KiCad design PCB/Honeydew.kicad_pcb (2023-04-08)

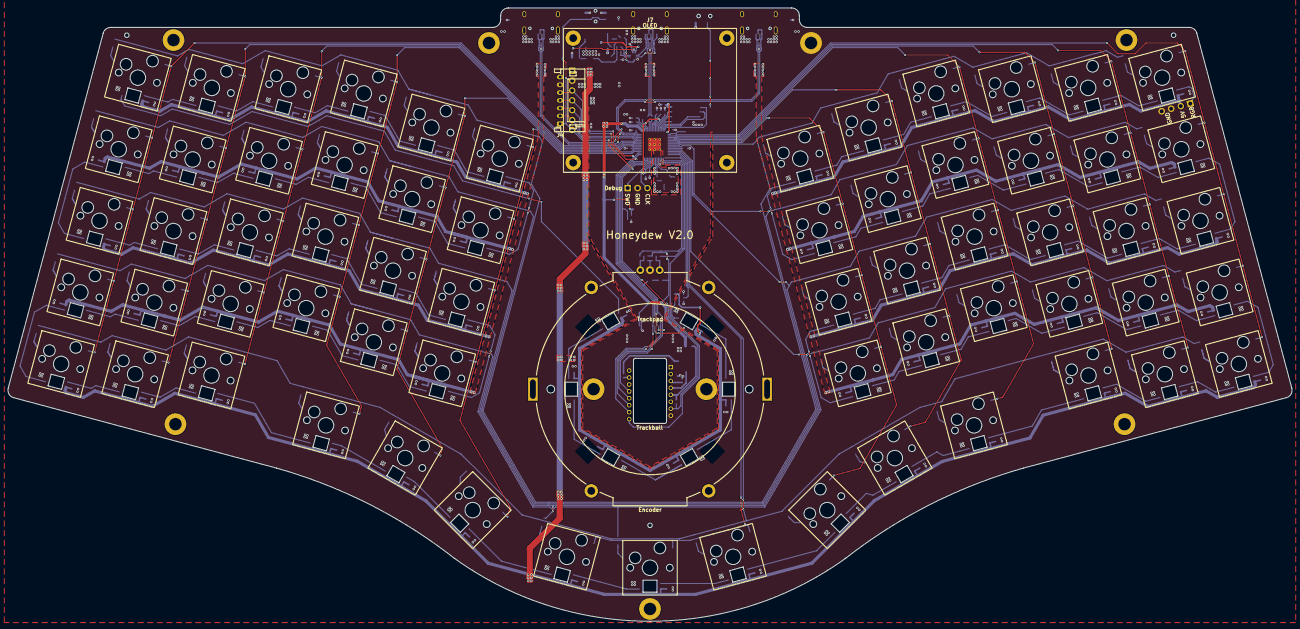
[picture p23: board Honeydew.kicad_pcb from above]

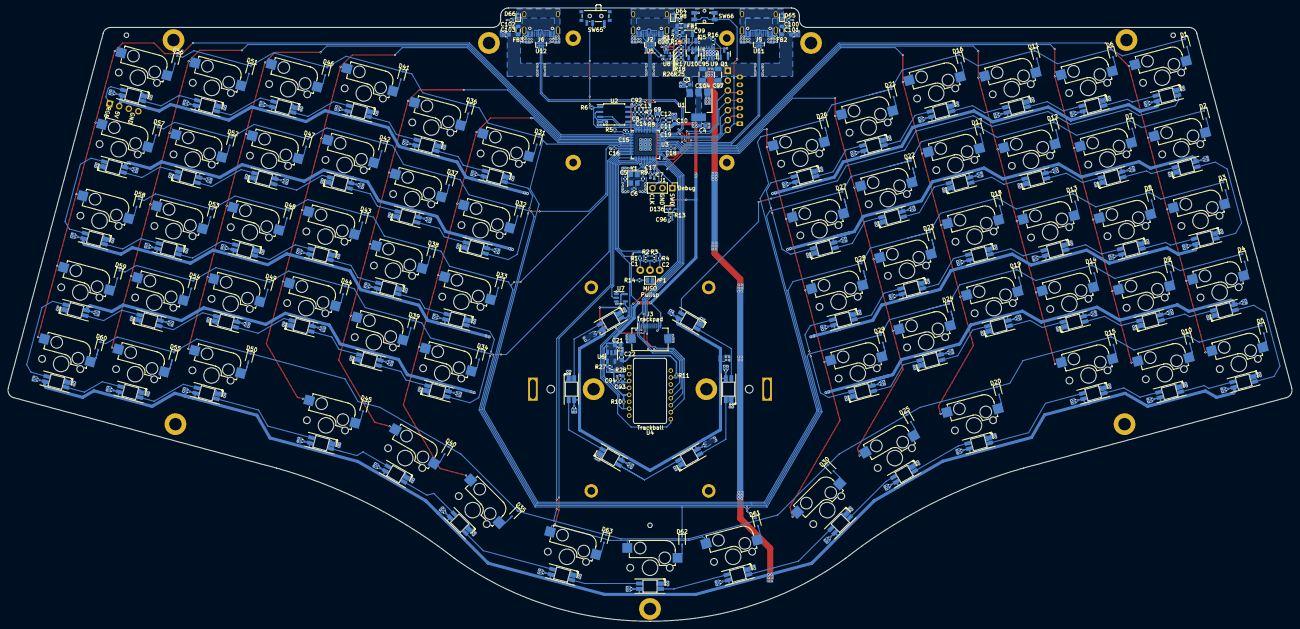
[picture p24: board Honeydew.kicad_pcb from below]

Board: 2 copper layers, 330.1 x 157.7 mm, 366 parts (356 on the bottom side), 206 nets.

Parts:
A1: Ariamelon Logo; Ariamelon_Logo_x3_CU
C1, C2, C98, C100, C102: 10n; C_0402_1005Metric
C3, C4, C93: 4u7; C_0603_1608Metric
C5, C6: 22p; C_0402_1005Metric
C7, C8, C11, C12, C13, C14, C15, C16, C17, C18, C19, C20, C23, C24, C25, C26, C27, C28, C29, C30, C31, C32, C33, C34, C35, C36, C37, C38, C39, C40, C41, C42, C43, C44, C45, C46, C47, C48, C49, C50, C51, C52, C53, C54, C55, C56, C57, C58, C59, C60, C61, C62, C63, C64, C65, C66, C67, C68, C69, C70, C71, C72, C73, C74, C75, C76, C77, C78, C79, C80, C81, C82, C83, C84, C85, C86, C87, C88, C89, C90, C91, C92, C94, C95, C96: 100n; C_0402_1005Metric
C9, C10, C21, C22, C99, C101, C103: 1u; C_0603_1608Metric
C97, C104: 47u; C_1206_3216Metric
D1, D2, D3, D4, D5, D6, D7, D8, D9, D10, D11, D12, D13, D14, D15, D16, D17, D18, D19, D20, D21, D22, D23, D24, D25, D26, D27, D28, D29, D30, D31, D32, D33, D34, D35, D36, D37, D38, D39, D40, D41, D42, D43, D44, D45, D46, D47, D48, D49, D50, D51, D52, D53, D54, D55, D56, D57, D58, D59, D60, D61, D62, D63, D136: 1N4148; D_SOD-323
D64, D65, D66: 5V; D_SOD-523
D67, D68, D69, D70, D71, D72, D73, D74, D75, D76, D77, D78, D79, D80, D81, D82, D83, D84, D85, D86, D87, D88, D89, D90, D91, D92, D93, D94, D95, D96, D97, D98, D99, D100, D101, D102, D103, D104, D105, D106, D107, D108, D109, D110, D111, D112, D113, D114, D115, D116, D117, D118, D119, D120, D121, D122, D123, D124, D125, D126, D127, D128, D129, D130, D131, D132, D133, D134, D135: SK6812MINI-E; YS-SK6812MINI-E
FB1, FB2, FB3: 60R@100MHz; L_0805_2012Metric
H1, H2, H3: Tooling Hole; JLC Tooling Hole
H4, H5, H6, H7, H8, H9, H10: M3; MountingHole_3.2mm_M3_Pad
J1: SWD; PinHeader_1x03_P2.54mm_Vertical
J2: USB In; HRO-TYPE-C-31-M-12
J3: Trackpad; Hirose_FH12-12S-0.5SH_1x12-1MP_P0.50mm_Horizontal
J4: OLED; JST_PH_S7B-PH-K_1x07_P2.00mm_Horizontal
J5: Split_L; HRO-TYPE-C-31-M-12
J6: Split_R; HRO-TYPE-C-31-M-12
J7: OLED; OLED_1.5_SSD1351_128x128
J9: RGB_EX; PinHeader_1x04_P2.54mm_Vertical_SIlkless
JP1: MISO_Pullup; SolderJumper-2_P1.3mm_Open_Pad1.0x1.5mm
Q1: 2N7002; SOT-23
Q5: AO3401A; SOT-23
R1, R2, R3, R4, R5, R10, R13, R14, R27: 10k; R_0402_1005Metric
R6, R9, R15: 1k; R_0402_1005Metric
R7, R8: 27; R_0402_1005Metric
R11: 39; R_0402_1005Metric
R12: 900k; R_0402_1005Metric
R16: 100k; R_0402_1005Metric
R17, R18: 270k; R_0402_1005Metric
R25: 220k; R_0402_1005Metric
R26: 82k; R_0402_1005Metric
R28: 15k; R_0402_1005Metric
SW1, SW2, SW3, SW4, SW5, SW6, SW7, SW8, SW9, SW10, SW11, SW12, SW13, SW14, SW15, SW16, SW17, SW18, SW19, SW20, SW21, SW22, SW23, SW24, SW25, SW26, SW27, SW28, SW29, SW30, SW31, SW32, SW33, SW34, SW35, SW36, SW37, SW38, SW39, SW40, SW41, SW42, SW43, SW44, SW45, SW46, SW47, SW48, SW49, SW50, SW51, SW52, SW53, SW54, SW55, SW56, SW57, SW58, SW59, SW60, SW61, SW62, SW63: CPG151101S11; MXOnly-1U-Hotswap
SW64: Encoder; PER60
SW65: Reset; SW_SPDT_PCM12
SW66: Reset; Panasonic_EVQPUL_EVQPUC
U1: AMS1117-3.3; SOT-223-3_TabPin2
U2: W25Q128JVS; SOIC-8_5.23x5.23mm_P1.27mm
U3: RP2040; QFN-56-1EP_7x7mm_P0.4mm_EP3.2x3.2mm_ThermalVias
U4: PMW3360DM-T2QU; IC_PMW3360DM-T2QU
U5, U11, U12: TPD4E05U06DQAR; USON-10_2.5x1.0mm_P0.5mm
U6: AP2127K-ADJ; SOT-23-5
U7: SN74AHCT1G125; SOT-23-5
U8: TUSB320LA; Texas_X2QFN-12_1.6x1.6mm_P0.4mm
U9: TPS2557; HVSON-8-1EP_3x3mm_P0.65mm_EP1.6x2.4mm
U10: LMV321; SOT-23-5
Y1: 12MHz; Crystal_SMD_3225-4Pin_3.2x2.5mm

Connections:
+1V1: C7.2, C8.2, C9.2, U3.23 (DVDD), U3.45 (VREG_VOUT), U3.50 (DVDD)
+2V: C22.1, R11.2, R28.1, U4.4 (VDD), U6.5 (VOUT)
+3V3: C4.2, C10.2, C11.2, C12.2, C13.2, C14.2, C15.2, C16.2, C17.2, C18.2, C19.2, C21.1, C92.2, D136.1 (K), J3.12, R2.2, R3.1, R5.1, R10.2, R13.1, R14.2, U1.2 (VO), U2.8 (VCC), U3.1 (IOVDD), U3.10 (IOVDD), U3.22 (IOVDD), U3.33 (IOVDD), U3.42 (IOVDD), U3.43 (ADC_AVDD), U3.44 (VREG_IN), U3.48 (USB_VDD), U3.49 (IOVDD), U4.5 (VDDIO), U6.1 (VIN), U6.3 (EN)
+5V: C20.2, C95.2, Q5.2 (S), R16.1, U8.12 (VDD), U9.2 (IN), U9.3 (IN), U9.4 (EN), U10.1 (+), U10.5 (V+)
+5VD: C3.2, C23.2, C24.1, C25.2, C26.2, C27.1, C28.2, C29.2, C30.1, C31.2, C32.2, C33.1, C34.2, C35.2, C36.1, C37.2, C38.2, C39.1, C40.2, C41.2, C42.1, C43.2, C44.2, C45.1, C46.2, C47.2, C48.1, C49.2, C50.2, C51.1, C52.2, C53.2, C54.1, C55.2, C56.2, C57.1, C58.2, C59.2, C60.1, C61.2, C62.2, C63.1, C64.2, C65.2, C66.1, C67.2, C68.2, C69.1, C70.2, C71.2, C72.1, C73.2, C74.2, C75.1, C76.2, C77.2, C78.1, C79.2, C80.2, C81.1, C82.2, C83.2, C84.1, C85.2, C86.2, C87.1, C88.2, C89.2, C90.1, C91.2, C97.2, C101.1, C103.1, C104.2, D67.1 (VDD), D68.1 (VDD), D69.1 (VDD), D70.1 (VDD), D71.1 (VDD), D72.1 (VDD), D73.1 (VDD), D74.1 (VDD), D75.1 (VDD), D76.1 (VDD), D77.1 (VDD), D78.1 (VDD), D79.1 (VDD), D80.1 (VDD), D81.1 (VDD), D82.1 (VDD), D83.1 (VDD), D84.1 (VDD), D85.1 (VDD), D86.1 (VDD), D87.1 (VDD), D88.1 (VDD), D89.1 (VDD), D90.1 (VDD), D91.1 (VDD), D92.1 (VDD), D93.1 (VDD), D94.1 (VDD), D95.1 (VDD), D96.1 (VDD), D97.1 (VDD), D98.1 (VDD), D99.1 (VDD), D100.1 (VDD), D101.1 (VDD), D102.1 (VDD), D103.1 (VDD), D104.1 (VDD), D105.1 (VDD), D106.1 (VDD), D107.1 (VDD), D108.1 (VDD), D109.1 (VDD), D110.1 (VDD), D111.1 (VDD), D112.1 (VDD), D113.1 (VDD), D114.1 (VDD), D115.1 (VDD), D116.1 (VDD), D117.1 (VDD), D118.1 (VDD), D119.1 (VDD), D120.1 (VDD), D121.1 (VDD), D122.1 (VDD), D123.1 (VDD), D124.1 (VDD), D125.1 (VDD), D126.1 (VDD), D127.1 (VDD), D128.1 (VDD), D129.1 (VDD), D130.1 (VDD), D131.1 (VDD), D132.1 (VDD), D133.1 (VDD), D134.1 (VDD), D135.1 (VDD), FB2.1, FB3.1, J4.7, J7.1, J9.2, U1.3 (VI), U7.5 (VCC), U9.6 (OUT), U9.7 (OUT)
/Comms - SPI/DC_OLED: J4.2, J7.6, U3.38 (GPIO26_ADC0)
/Comms - SPI/MISO: J3.2, JP1.2 (B), U3.27 (GPIO16), U4.12 (MISO)
/Comms - SPI/MOSI: J3.5, J4.5, J7.3, U3.30 (GPIO19), U4.11 (MOSI)
/Comms - SPI/MOTION: J3.4, U3.16 (GPIO13), U4.9 (MOTION)
/Comms - SPI/SCK: J3.1, J4.4, J7.4, U3.29 (GPIO18), U4.10 (SCLK)
/Comms - SPI/SS_OLED: J4.3, J7.5, U3.39 (GPIO27_ADC1)
/Comms - SPI/SS_TB: J3.3, U3.28 (GPIO17), U4.13 (NCS)
/Comms - SPI/~RST: C96.2, D136.2 (A), J4.1, J7.7, R10.1, R13.2, SW66.2 (B), U3.26 (RUN), U4.7 (NRESET)
/Comms - Split/RX: J5.A7 (D-), J5.B7 (D-), J6.A7 (D-), J6.B7 (D-), U3.40 (GPIO28_ADC2), U11.4 (IO3), U11.7 (NC), U12.4 (IO3), U12.7 (NC)
/Comms - Split/TX: J5.A6 (D+), J5.B6 (D+), J6.A6 (D+), J6.B6 (D+), U3.41 (GPIO29_ADC3), U11.2 (IO2), U11.9 (NC), U12.2 (IO2), U12.9 (NC)
/Comms - USB/CC1: J2.A5 (CC1), U5.5 (IO4), U5.6 (NC), U8.1 (CC1)
/Comms - USB/CC2: J2.B5 (CC2), U5.1 (IO1), U5.10 (NC), U8.2 (CC2)
/Comms - USB/D+: J2.A6 (D+), J2.B6 (D+), R7.1, U5.2 (IO2), U5.9 (NC)
/Comms - USB/D-: J2.A7 (D-), J2.B7 (D-), R8.1, U5.4 (IO3), U5.7 (NC)
/MCU/COL0: SW1.2 (B), SW2.2 (B), SW3.2 (B), SW4.2 (B), SW5.2 (B), U3.37 (GPIO25)
/MCU/COL1: SW6.2 (B), SW7.2 (B), SW8.2 (B), SW9.2 (B), SW10.2 (B), U3.36 (GPIO24)
/MCU/COL2: SW11.2 (B), SW12.2 (B), SW13.2 (B), SW14.2 (B), SW15.2 (B), U3.35 (GPIO23)
/MCU/COL3: SW16.2 (B), SW17.2 (B), SW18.2 (B), SW19.2 (B), SW20.2 (B), U3.34 (GPIO22)
/MCU/COL4: SW21.2 (B), SW22.2 (B), SW23.2 (B), SW24.2 (B), SW25.2 (B), U3.32 (GPIO21)
/MCU/COL5: SW26.2 (B), SW27.2 (B), SW28.2 (B), SW29.2 (B), SW30.2 (B), U3.31 (GPIO20)
/MCU/COL6: SW31.2 (B), SW32.2 (B), SW33.2 (B), SW34.2 (B), SW35.2 (B), U3.7 (GPIO5)
/MCU/COL7: SW36.2 (B), SW37.2 (B), SW38.2 (B), SW39.2 (B), SW40.2 (B), U3.6 (GPIO4)
/MCU/COL8: SW41.2 (B), SW42.2 (B), SW43.2 (B), SW44.2 (B), SW45.2 (B), U3.5 (GPIO3)
/MCU/COL9: SW46.2 (B), SW47.2 (B), SW48.2 (B), SW49.2 (B), SW50.2 (B), U3.4 (GPIO2)
/MCU/COL10: SW51.2 (B), SW52.2 (B), SW53.2 (B), SW54.2 (B), SW55.2 (B), U3.3 (GPIO1)
/MCU/COL11: SW56.2 (B), SW57.2 (B), SW58.2 (B), SW59.2 (B), SW60.2 (B), U3.2 (GPIO0)
/MCU/COLM: SW61.2 (B), SW62.2 (B), SW63.2 (B), U3.14 (GPIO11)
/MCU/RGB: D67.4 (DIN), U7.4 (Y)
/MCU/ROTA: R1.1, U3.17 (GPIO14)
/MCU/ROTB: R4.2, U3.18 (GPIO15)
/MCU/ROW0: D1.1 (K), D6.1 (K), D11.1 (K), D16.1 (K), D21.1 (K), D26.1 (K), D31.1 (K), D36.1 (K), D41.1 (K), D46.1 (K), D51.1 (K), D56.1 (K), U3.8 (GPIO6)
/MCU/ROW1: D2.1 (K), D7.1 (K), D12.1 (K), D17.1 (K), D22.1 (K), D27.1 (K), D32.1 (K), D37.1 (K), D42.1 (K), D47.1 (K), D52.1 (K), D57.1 (K), U3.9 (GPIO7)
/MCU/ROW2: D3.1 (K), D8.1 (K), D13.1 (K), D18.1 (K), D23.1 (K), D28.1 (K), D33.1 (K), D38.1 (K), D43.1 (K), D48.1 (K), D53.1 (K), D58.1 (K), D61.1 (K), U3.11 (GPIO8)
/MCU/ROW3: D4.1 (K), D9.1 (K), D14.1 (K), D19.1 (K), D24.1 (K), D29.1 (K), D34.1 (K), D39.1 (K), D44.1 (K), D49.1 (K), D54.1 (K), D59.1 (K), D62.1 (K), U3.12 (GPIO9)
/MCU/ROW4: D5.1 (K), D10.1 (K), D15.1 (K), D20.1 (K), D25.1 (K), D30.1 (K), D35.1 (K), D40.1 (K), D45.1 (K), D50.1 (K), D55.1 (K), D60.1 (K), D63.1 (K), U3.13 (GPIO10)
/PSU/~1500mA_EN: R18.2, R25.2, U8.7 (SDA/OUT1)
/PSU/~3000mA_EN: R26.2, U8.8 (SCL/OUT2)
/PSU/~EN: Q1.3 (D), U8.11 (~EN)
GND: C1.1, C2.1, C3.1, C4.1, C5.1, C6.1, C7.1, C8.1, C9.1, C10.1, C11.1, C12.1, C13.1, C14.1, C15.1, C16.1, C17.1, C18.1, C19.1, C20.1, C21.2, C22.2, C23.1, C24.2, C25.1, C26.1, C27.2, C28.1, C29.1, C30.2, C31.1, C32.1, C33.2, C34.1, C35.1, C36.2, C37.1, C38.1, C39.2, C40.1, C41.1, C42.2, C43.1, C44.1, C45.2, C46.1, C47.1, C48.2, C49.1, C50.1, C51.2, C52.1, C53.1, C54.2, C55.1, C56.1, C57.2, C58.1, C59.1, C60.2, C61.1, C62.1, C63.2, C64.1, C65.1, C66.2, C67.1, C68.1, C69.2, C70.1, C71.1, C72.2, C73.1, C74.1, C75.2, C76.1, C77.1, C78.2, C79.1, C80.1, C81.2, C82.1, C83.1, C84.2, C85.1, C86.1, C87.2, C88.1, C89.1, C90.2, C91.1, C92.1, C93.2, C94.1, C95.1, C96.1, C97.1, C98.1, C99.2, C100.1, C101.2, C102.1, C103.2, C104.1, D64.2 (A), D65.2 (A), D66.2 (A), D67.3 (VSS), D68.3 (VSS), D69.3 (VSS), D70.3 (VSS), D71.3 (VSS), D72.3 (VSS), D73.3 (VSS), D74.3 (VSS), D75.3 (VSS), D76.3 (VSS), D77.3 (VSS), D78.3 (VSS), D79.3 (VSS), D80.3 (VSS), D81.3 (VSS), D82.3 (VSS), D83.3 (VSS), D84.3 (VSS), D85.3 (VSS), D86.3 (VSS), D87.3 (VSS), D88.3 (VSS), D89.3 (VSS), D90.3 (VSS), D91.3 (VSS), D92.3 (VSS), D93.3 (VSS), D94.3 (VSS), D95.3 (VSS), D96.3 (VSS), D97.3 (VSS), D98.3 (VSS), D99.3 (VSS), D100.3 (VSS), D101.3 (VSS), D102.3 (VSS), D103.3 (VSS), D104.3 (VSS), D105.3 (VSS), D106.3 (VSS), D107.3 (VSS), D108.3 (VSS), D109.3 (VSS), D110.3 (VSS), D111.3 (VSS), D112.3 (VSS), D113.3 (VSS), D114.3 (VSS), D115.3 (VSS), D116.3 (VSS), D117.3 (VSS), D118.3 (VSS), D119.3 (VSS), D120.3 (VSS), D121.3 (VSS), D122.3 (VSS), D123.3 (VSS), D124.3 (VSS), D125.3 (VSS), D126.3 (VSS), D127.3 (VSS), D128.3 (VSS), D129.3 (VSS), D130.3 (VSS), D131.3 (VSS), D132.3 (VSS), D133.3 (VSS), D134.3 (VSS), D135.3 (VSS), H4.1, J1.2, J2.A1 (GND), J2.A12 (GND), J2.S1 (SHIELD), J3.11, J3.MP (MountPin), J4.6, J5.A1 (GND), J5.A12 (GND), J5.S1 (SHIELD), J6.A1 (GND), J6.A12 (GND), J6.S1 (SHIELD), J7.2, J9.3, J9.4, Q1.2 (S), R17.2, R27.2, SW64.C, SW65.1 (A), SW66.1 (A), U1.1 (GND), U2.4 (GND), U3.19 (TESTEN), U3.57 (GND), U4.8 (GND), U5.3 (GND), U5.8 (GND), U6.2 (GND), U7.1 (~OE), U7.3 (GND), U8.3 (PORT), U8.10 (GND), U9.1 (GND), U9.9 (GND), U10.2 (V-), U11.3 (GND), U11.8 (GND), U12.3 (GND), U12.8 (GND), Y1.2, Y1.4
unnamed: C1.2, R1.2, R2.1, SW64.A
unnamed: C2.2, R3.2, R4.1, SW64.B
unnamed: C6.2, R9.1, Y1.3
unnamed: D1.2 (A), SW1.1 (A)
unnamed: D2.2 (A), SW2.1 (A)
unnamed: D3.2 (A), SW3.1 (A)
unnamed: D4.2 (A), SW4.1 (A)
unnamed: D5.2 (A), SW5.1 (A)
unnamed: D6.2 (A), SW6.1 (A)
unnamed: D7.2 (A), SW7.1 (A)
unnamed: D8.2 (A), SW8.1 (A)
unnamed: D9.2 (A), SW9.1 (A)
unnamed: D10.2 (A), SW10.1 (A)
unnamed: D11.2 (A), SW11.1 (A)
unnamed: D12.2 (A), SW12.1 (A)
unnamed: D13.2 (A), SW13.1 (A)
unnamed: D14.2 (A), SW14.1 (A)
unnamed: D15.2 (A), SW15.1 (A)
unnamed: D16.2 (A), SW16.1 (A)
unnamed: D17.2 (A), SW17.1 (A)
unnamed: D18.2 (A), SW18.1 (A)
unnamed: D19.2 (A), SW19.1 (A)
unnamed: D20.2 (A), SW20.1 (A)
unnamed: D21.2 (A), SW21.1 (A)
unnamed: D22.2 (A), SW22.1 (A)
unnamed: D23.2 (A), SW23.1 (A)
unnamed: D24.2 (A), SW24.1 (A)
unnamed: D25.2 (A), SW25.1 (A)
unnamed: D26.2 (A), SW26.1 (A)
unnamed: D27.2 (A), SW27.1 (A)
unnamed: D28.2 (A), SW28.1 (A)
unnamed: D29.2 (A), SW29.1 (A)
unnamed: D30.2 (A), SW30.1 (A)
unnamed: D31.2 (A), SW31.1 (A)
unnamed: D32.2 (A), SW32.1 (A)
unnamed: D33.2 (A), SW33.1 (A)
unnamed: D34.2 (A), SW34.1 (A)
unnamed: D35.2 (A), SW35.1 (A)
unnamed: D36.2 (A), SW36.1 (A)
unnamed: D37.2 (A), SW37.1 (A)
unnamed: D38.2 (A), SW38.1 (A)
unnamed: D39.2 (A), SW39.1 (A)
unnamed: D40.2 (A), SW40.1 (A)
unnamed: D41.2 (A), SW41.1 (A)
unnamed: D42.2 (A), SW42.1 (A)
unnamed: D43.2 (A), SW43.1 (A)
unnamed: D44.2 (A), SW44.1 (A)
unnamed: D45.2 (A), SW45.1 (A)
unnamed: D46.2 (A), SW46.1 (A)
unnamed: D47.2 (A), SW47.1 (A)
unnamed: D48.2 (A), SW48.1 (A)
unnamed: D49.2 (A), SW49.1 (A)
unnamed: D50.2 (A), SW50.1 (A)
unnamed: D51.2 (A), SW51.1 (A)
unnamed: D52.2 (A), SW52.1 (A)
unnamed: D53.2 (A), SW53.1 (A)
unnamed: D54.2 (A), SW54.1 (A)
unnamed: D55.2 (A), SW55.1 (A)
unnamed: D56.2 (A), SW56.1 (A)
unnamed: D57.2 (A), SW57.1 (A)
unnamed: D58.2 (A), SW58.1 (A)
unnamed: D59.2 (A), SW59.1 (A)
unnamed: D60.2 (A), SW60.1 (A)
unnamed: D61.2 (A), SW61.1 (A)
unnamed: D62.2 (A), SW62.1 (A)
unnamed: D63.2 (A), SW63.1 (A)
unnamed: C98.2, D64.1 (K), FB1.2, J2.A4 (VBUS), J2.A9 (VBUS)
unnamed: C100.2, D65.1 (K), FB2.2, J5.A4 (VBUS), J5.A9 (VBUS)
unnamed: C102.2, D66.1 (K), FB3.2, J6.A4 (VBUS), J6.A9 (VBUS)
unnamed: D67.2 (DOUT), D68.4 (DIN)
unnamed: D68.2 (DOUT), D69.4 (DIN)
unnamed: D69.2 (DOUT), D70.4 (DIN)
unnamed: D70.2 (DOUT), D71.4 (DIN)
unnamed: D71.2 (DOUT), D72.4 (DIN)
unnamed: D72.2 (DOUT), D73.4 (DIN)
unnamed: D73.2 (DOUT), D78.4 (DIN)
unnamed: D74.4 (DIN), D79.2 (DOUT)
unnamed: D74.2 (DOUT), D75.4 (DIN)
unnamed: D75.2 (DOUT), D80.4 (DIN)
unnamed: D76.4 (DIN), D81.2 (DOUT)
unnamed: D76.2 (DOUT), D77.4 (DIN)
unnamed: D77.2 (DOUT), D82.4 (DIN)
unnamed: D78.2 (DOUT), D83.4 (DIN)
unnamed: D79.4 (DIN), D84.2 (DOUT)
unnamed: D80.2 (DOUT), D85.4 (DIN)
unnamed: D81.4 (DIN), D86.2 (DOUT)
unnamed: D82.2 (DOUT), D87.4 (DIN)
unnamed: D83.2 (DOUT), D88.4 (DIN)
unnamed: D84.4 (DIN), D89.2 (DOUT)
unnamed: D85.2 (DOUT), D90.4 (DIN)
unnamed: D86.4 (DIN), D91.2 (DOUT)
unnamed: D87.2 (DOUT), D92.4 (DIN)
unnamed: D88.2 (DOUT), D93.4 (DIN)
unnamed: D89.4 (DIN), D94.2 (DOUT)
unnamed: D90.2 (DOUT), D95.4 (DIN)
unnamed: D91.4 (DIN), D96.2 (DOUT)
unnamed: D92.2 (DOUT), D97.4 (DIN)
unnamed: D93.2 (DOUT), D98.4 (DIN)
unnamed: D94.4 (DIN), D99.2 (DOUT)
unnamed: D98.2 (DOUT), D99.4 (DIN)
unnamed: D95.2 (DOUT), D100.4 (DIN)
unnamed: D100.2 (DOUT), D101.4 (DIN)
unnamed: D96.4 (DIN), D101.2 (DOUT)
unnamed: D97.2 (DOUT), D102.4 (DIN)
unnamed: D102.2 (DOUT), D103.4 (DIN)
unnamed: D103.2 (DOUT), D104.4 (DIN)
unnamed: D104.2 (DOUT), D105.4 (DIN)
unnamed: D105.2 (DOUT), D110.4 (DIN)
unnamed: D106.4 (DIN), D107.2 (DOUT)
unnamed: D106.2 (DOUT), D111.4 (DIN)
unnamed: D107.4 (DIN), D112.2 (DOUT)
unnamed: D108.4 (DIN), D109.2 (DOUT)
unnamed: D108.2 (DOUT), D113.4 (DIN)
unnamed: D109.4 (DIN), D114.2 (DOUT)
unnamed: D110.2 (DOUT), D115.4 (DIN)
unnamed: D111.2 (DOUT), D116.4 (DIN)
unnamed: D112.4 (DIN), D117.2 (DOUT)
unnamed: D113.2 (DOUT), D118.4 (DIN)
unnamed: D114.4 (DIN), D119.2 (DOUT)
unnamed: D115.2 (DOUT), D120.4 (DIN)
unnamed: D116.2 (DOUT), D121.4 (DIN)
unnamed: D117.4 (DIN), D122.2 (DOUT)
unnamed: D118.2 (DOUT), D123.4 (DIN)
unnamed: D119.4 (DIN), D124.2 (DOUT)
unnamed: D120.2 (DOUT), D125.4 (DIN)
unnamed: D121.2 (DOUT), D126.4 (DIN)
unnamed: D122.4 (DIN), D127.2 (DOUT)
unnamed: D123.2 (DOUT), D128.4 (DIN)
unnamed: D124.4 (DIN), D129.2 (DOUT)
unnamed: D125.2 (DOUT), D130.4 (DIN)
unnamed: D126.2 (DOUT), D131.4 (DIN)
unnamed: D127.4 (DIN), D132.2 (DOUT)
unnamed: D128.2 (DOUT), D133.4 (DIN)
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

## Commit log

2023-03-03 V1.0 initial update.
    [Comms.kicad_sch, Honeydew.kicad_pcb, Honeydew.kicad_sch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]
2023-03-04 Changed RGB LED voltage to 5V.
    [Honeydew.kicad_pcb, Honeydew.kicad_sch, MCU.kicad_sch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]
2023-03-04 Massive mistake corrections and clarifications.
    [Comms.kicad_sch, Honeydew.kicad_sch, MCU.kicad_sch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]
2023-03-04 Fixed error in MCU sheet. Changed flash symbol to the one used in Kicad 7.
    [MCU.kicad_sch]
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2023-03-08 Rewording of readme. Added files for JLC PCBA. Changed USB C connector and moved it away from board.
    [BOM-Honeydew.csv, Comms.kicad_sch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]
2023-03-08 Added plate DXF and gerbers and case STEP files.
    [Bottom.step, Knob.step, Plate.dxf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]
2023-03-09 Shifted MCU up to reduce length of USB traces. Added holes for JLC assembly.
    [BOM-Honeydew.csv, Bottom.step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]
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2023-03-10 Changed center of switches for JLC assembly.
    [BOM-Honeydew.csv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]
2023-03-11 Added PH2.0 header for OLED. Changed plate to accommodate headers.
    [BOM-Honeydew.csv, Comms.kicad_sch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]
2023-03-13 V1.1 update.
    [BOM-Honeydew.csv, Comms.kicad_sch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]
2023-03-14 Fixed top and bottom case STEP files.
    [Bottom.step, Top.step]
2023-03-15 Minor fix to silk.
    [BOM-Honeydew.csv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]
2023-03-24 Added level shifter to the RGB signal, just in case.
    [BOM-Honeydew.csv, Bottom.step, Comms.kicad_sch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]
2023-03-25 Changed knob and trackpad mount STEP files
    [Knob.step, Mount.step, Trackpad Mount.step]
2023-03-31 More V1.1 updates
    [BOM-Honeydew.csv, Bottom.step, Comms.kicad_sch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]
2023-04-02 Initial V2.0 update.
    [BOM-Honeydew.csv, Bottom.step, Comms.kicad_sch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]
2023-04-03 Additional changes.
    [BOM-Honeydew.csv, Expansion.kicad_sch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]
2023-04-03 Moved position of USB-C ports further out.
    [CPL-Honeydew.csv, Honeydew-CuBottom.gbr, Honeydew-CuTop.gbr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]
2023-04-08 Large update.
    [BOM-Honeydew.csv, Comms - Split.kicad_sch, Comms-SPI.kicad_sch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]
2023-04-08 Added large caps to output of TPS2557. Updated STEP file and file data.
    [BOM-Honeydew.csv, Comms - SPI.kicad_sch, Comms - Split.kicad_sch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]
2023-04-08 Added back ground plane. Fixed rotation of production files.
    [BOM-Honeydew.csv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]
2023-04-10 Shrunk size of PCB.
    [BOM-Honeydew.csv, Comms - Split.kicad_sch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]
2023-04-10 Added plate DXF and gerbers. Removed split comms ports and ideal diode.
    [BOM-Honeydew.csv, Comms - USB.kicad_sch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]
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2023-04-25 3/4-done update.
    Added current and voltage measurement for VBUS in and current measurement for the RGB output. Added PMOS power switch to fully turn off RGB LEDs when not in use. Rerouted the PCB. Moved OLED ribbon c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
    [Honeydew.kicad_sch, MCU.kicad_sch, Matrix.kicad_sch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]
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2023-05-15 Finished routing RGB LEDs.
    [BOM-Honeydew.csv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]
2023-05-19 Improved switch footprints and changed LDO.
    [BOM-Honeydew.csv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]
2023-05-20 Added thumb wheel encoder in 2u slot.
    [BOM-Honeydew.csv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]
2023-06-11 Updated BOM. Added new tentative plate file.
    [BOM-Honeydew.csv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]
2023-06-24 Update in progress (will be squashed)
    [Plate.kicad_pcb]
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2023-06-30 Routed 13V EN pin to the MCU. Removed solder jumper.
    [Honeydew.kicad_sch, MCU.kicad_sch, PSU.kicad_sch]
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2023-07-14 14/07/2023 update
    Replaced 1N4148 switch diodes with BAV70. Replaced switch footprints with combination MX/Choc hotswap footprints. Replaced flash IC with much smaller version. Removed buttons and USB-C port and replaced it with an FFC connector for [Galia](https://github.com/Ariamelon/Galia) (a USB-C daughterboard designed specifically for the Honeydew). Added case STEP file and renders.
    [BOM-Honeydew.csv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]
2023-07-14 Added footprint for PTS645 SMT and THT parts to the mouse switch in the thumb encoder.
    [BOM-Honeydew.csv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]
2023-07-16 16/07/2023 update
    Updated case file. Added individual case files. Added kicad plate files.
    [Case Bottom.step, Case Top.step, Knob.step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]
2023-07-17 17/07/2023 update
    Changed 20 pin FFC connector to 14 pin JST SH connector. Repositioned components.
    [BOM-Honeydew.csv, Case Top.step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]
2023-07-18 18/07/2023 update.
    Changed JST connector back to 20 pin FFC. Centered connector. Increased size of PMW3360 cutout.
    [BOM-Honeydew.csv, Case Bottom.step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]
2023-07-21 21/07/2023 update.
    Fixed routing. Changed 20 pin FFC to 7 pin and 8 pin JST SH connector.
    [BOM-Honeydew.csv, Case Bottom.step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]
2023-07-26 25/07/2023 update
    Changed 8 pin JST SH connector to 6 pin. Pushed JST connectors back. Improved 3D model of SSD1351. Minor fix to PER56 footprint.
    [BOM-Honeydew.csv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]
2023-07-26 26/07/2023 update
    Sent to JLC (V3.0 release version). Slightly increased size of screw hole pads. Added two more screw holes. Added mounting holes to plate. Flipped gerbers for scrollwheel plate.
    [BOM-Honeydew.csv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]
2023-07-29 28/07/2023 update
    Removed center ring encoder, cirque trackpad and PMW3360 support. Added VIK header and hole in the center of the PCB for the Kiwano. Changed JST connectors back to 20 pin FFC. Total rearrangement of 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
    [BOM-Honeydew.csv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]
2023-07-30 30/07/2023 update
    Added VIK keyboard certification card. Added USB connector back to PCB, but left the two buttons on a separate daughterboard. Modified case to accommodate large VIK module.
    [BOM-Honeydew.csv, Case Bottom.step, Case Top.step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]
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2023-07-31 31/07/2023 update
    Removed button daughterboard. Reduced size of case and gaskets and added locating features. Added o-ring mounting for the PCB to the bottom case. Added fittings BOM.
    [BOM-Honeydew.csv, Case Bottom.step, Case Top.step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]
2023-08-01 01/08/2023 update
    Removed 3D files for trackpad mount and knob, moved to Kiwano repository. Increased size of center hole in plate. Increased size of center hole in plate. Added renders with trackball configurations (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
    [Knob.step, Plate 2u.dxf, Plate 2u.kicad_pcb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]
2023-08-05 04/08/2023 update
    Updated SK6812 MINI-E and switch footprints. Changed VIK FFC to FH12. Fixed VIK footprint. Replaced second TPS2595 with AO3401 PFET. Fixed trackpad mount, thumb scroll wheel and scroll wheel mount.
    [BOM-Honeydew.csv, Honeydew.kicad_sch, MCU.kicad_sch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]
2023-08-05 08/05/2023 update
    Fixed switch and SK6812 MINI-E footprints to get rid of DRC errors. Fixed EC10 footprint and merged together PTS645 and D2F footprints. Fixed plate files to fit JLC 1.6mm minimum slot specification. Added fusion file for overall design.
    [BOM-Honeydew.csv, Honeydew.kicad_sch, MCU.kicad_sch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]
2023-08-07 06/08/2023 update
    Changed switch footprint back to MX only, as it's too much money to risk on an experimental footprint, and rerouted the relevant traces. Cleaned up footprint library by removing many unused footprints.
    [BOM-Honeydew.csv, Honeydew.kicad_sch, MCU.kicad_sch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]
2023-08-08 08/08/2023 update
    Fixed case render.
2023-08-16 16/08/2023 update
    Updated to V3.1. Fixed VIK wiring (RGB and SDA were swapped). Added another BAV70 for the bottom button in the thumb cluster. Added DNP attribute to R15. Added jumper for VIK 5V rail.
    [BOM-Honeydew.csv, Honeydew.kicad_sch, MCU.kicad_sch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]
2023-08-17 17/08/2023 update
    Moved gasket mounts from plate to PCB. Changed USB C connector. Modified case to accommodate. Tweaked thumb scroll holder.
    [BOM-Honeydew.csv, Case Bottom.step, Case Top.step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]
2023-08-27 27/08/2023 update
    Added unified library for all symbols, footprints and 3D files. Changed MCU to STM32F072RBT6. Removed OLED, voltage and current sensing, USB CC circuitry and shift registers. Changed ESD protection c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
    [BOM-Honeydew.csv, Case Bottom.step, Case Top.step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]
2023-08-28 28/08/2023 update
    Added test points for VIK connector. Refined case and scrollwheel design. Added pull-up resistor to RGB trace. Added Acheron single-push reset circuit. Updated STEP files.
    [BOM-Honeydew.csv, Case Bottom.step, Honeydew.kicad_sch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]
2023-08-29 29/08/2023 update
    Reassigned I2C pins due to DMA issues and rerouted board. Added test point for BOOT0. Added additional ground vias.
    [BOM-Honeydew.csv, Honeydew.kicad_sch, MCU.kicad_sch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]
2023-09-02 02/09/2023 update
    Added ribs to bottom case for less warping, deformation and shrinkage risk. Updated library.
    [Case Bottom.step]
2023-09-27 27/09/2023 update
    Added image. Small change to scrollwheel 3D file for smoother scrolling.
    [Scrollwheel.step]
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

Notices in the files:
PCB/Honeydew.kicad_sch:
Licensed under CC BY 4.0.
